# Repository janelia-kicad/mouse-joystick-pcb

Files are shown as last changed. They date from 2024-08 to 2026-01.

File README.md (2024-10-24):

- [Repository Info](#org848bbb8)
- [Images](#org07a21c3)
- [Schematic](#org23b0c57)
- [PCB](#orged9e501)
- [Bill of Materials](#org9387ca8)
- [Notes](#orgdb3690e)
- [Development](#org3c101aa)

    <!-- This file is generated automatically from metadata -->
    <!-- File edits may be overwritten! -->

# Repository Info

-   Project Name: mouse-joystick-pcb
-   Synopsis: Janelia Dudman lab PCB for the mouse joystick rig.
-   Documentation Version: 1.0.0
-   Pcb Version: 1.0
-   Enclosure Version: 1.0
-   Supplemental BOM Version: 1.0.0
-   Release Date: 2024-10-24
-   Creation Date: 2017-08-14
-   Kicad Version: 7.0.11
-   License: BSD-3-Clause
-   URL: <https://github.com/janelia-kicad/mouse-joystick-pcb>
-   Author: Peter Polidoro
-   Email: peter@polidoro.io
-   Copyright: 2024 Howard Hughes Medical Institute
-   References:
    -   <https://www.transducertechniques.com/rts-torque-sensor.aspx>
    -   <https://placidindustries.com/products/brakes/magnetic-particle-brakes/magnetic-particle-brake-b5z/>
    -   <https://www.newark.com/broadcom-limited/hedr-5421-ep111/encoder-incremental-2-ch/dp/58Y4773>
    -   <https://www.linengineering.com/products/stepper-motors/hybrid-stepper-motors/208-series/208-13-01/WO-208-13-01D>
    -   <https://www.pololu.com/product/2267>

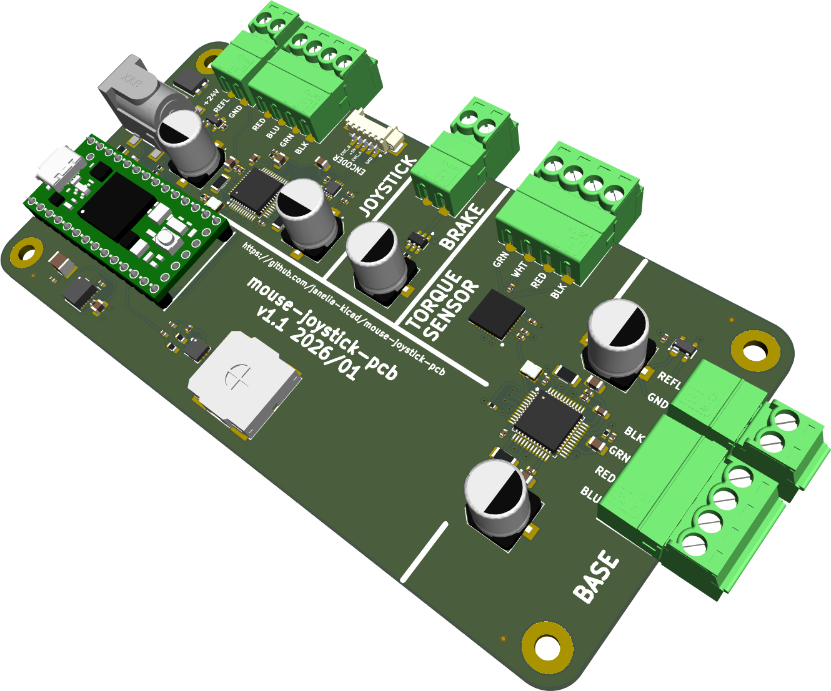
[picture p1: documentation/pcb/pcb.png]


# Images

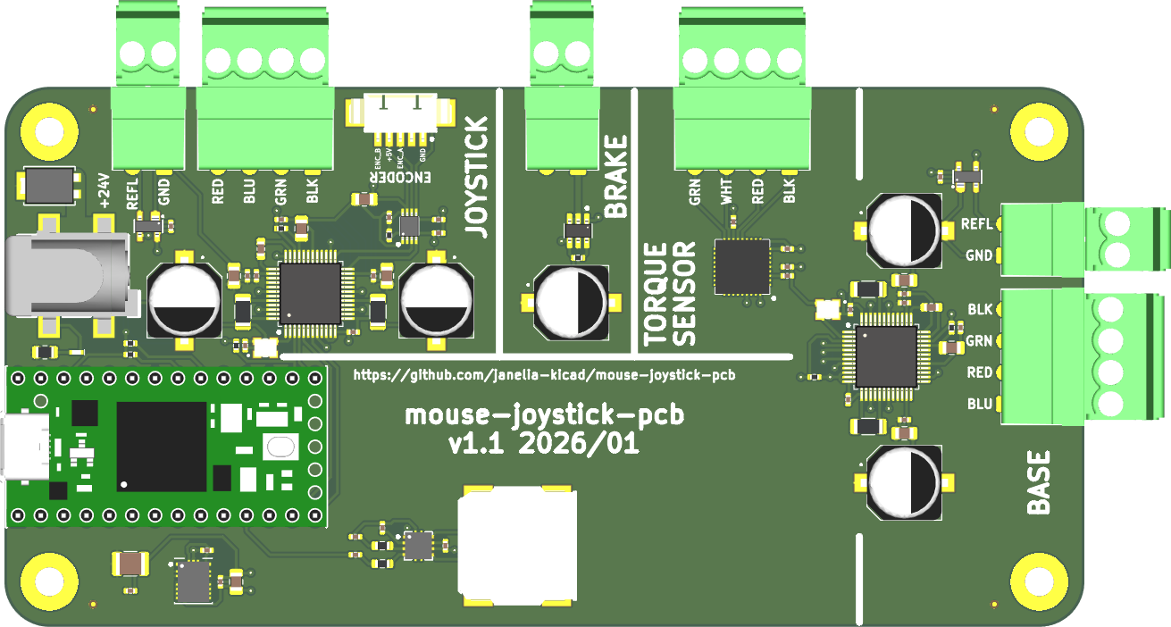
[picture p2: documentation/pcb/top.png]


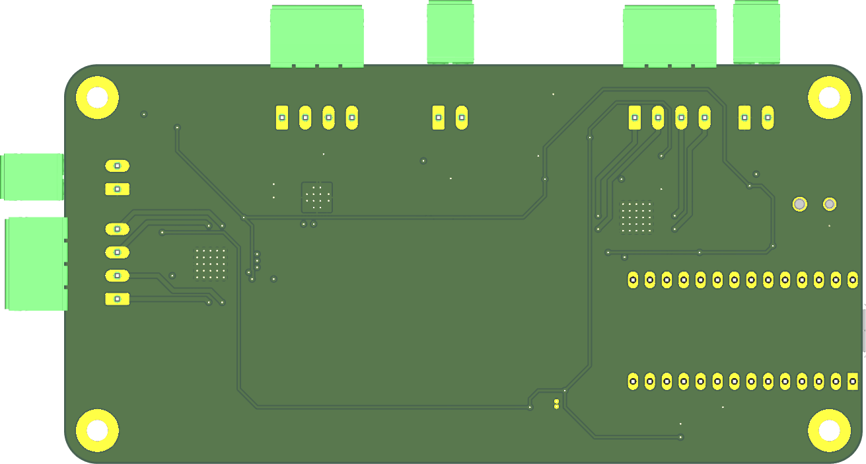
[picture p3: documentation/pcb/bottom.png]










# Schematic

[./documentation/schematic/mouse-joystick-pcb.pdf](./documentation/schematic/mouse-joystick-pcb.pdf)



















# PCB











# Bill of Materials

## Board

| Item | Synopsis | Manufacturer Part Number | Manufacturer | Quantity | Reference(s) | Package |
|---- |--- |--- |--- |--- |--- |--- |
| 1 | CONN HDR 14POS 0.1 GOLD PCB | PPPC141LFBN-RC | Sullins Connector Solutions | 1 | A401 | |
| 2 | 50V 3.3uF | FS32X335K500EGG | PSA(Prosperity Dielectrics) | 1 | C301 | 1210 |
| 3 | CAP CER 0.1UF 100V X5R | GRM155R62A104KE14D | Murata Electronics | 20 | C302 C501 C502 C504 C505 C508 C509 C510 C511 C516 C701 C702 C704 C705 C708 C709 C901 C902 C903 C904 | 0402 |
| 4 | CAP CER 1UF 25V X5R | GRT155R61E105KE01D | Murata Electronics | 2 | C303 C304 | 0402 |
| 5 | CAP CER 47UF 10V X5R | CGA0805X5R476M100MT | HRE | 3 | C305 C507 C707 | 0805 |
| 6 | CAP CER 0.022UF 100V X7R | GCM188R72A223KA37D | Murata Electronics | 2 | C503 C703 | 0603 |
| 7 | CAP CER 0.47UF 35V X5R | GRT155R6YA474KE01D | Murata Electronics | 2 | C506 C706 | 0402 |
| 8 | CAP CER 2.2UF 100V X7T 0805 | GRM21BD72A225KE01L | Murata Electronics | 5 | C512 C513 C517 C710 C711 | 0805 |
| 9 | CAP ALUM 100UF 20% 50V SMD | EEEHAH101UAP | Panasonic Electronic Components | 5 | C514 C515 C712 C713 C801 | SMD D8xL10.2mm |
| 10 | CAP CER 0.22UF 25V X6S | GRT155C81E224KE01D | Murata Electronics | 3 | C601 C602 C604 | 0402 |
| 11 | CAP CER 1UF 35V X5R | CL05A105KL5NRNC | Samsung Electro-Mechanics | 1 | C603 | 0402 |
| 12 | 50V 15A PowerDI-5 Super Barrier Rectifier | SBRT15U50SP5-13 | Diodes Incorporated | 1 | D301 | PowerDI-5 |
| 13 | LED RED CLEAR CHIP SMD | APHHS1005SURCK | Kingbright | 1 | D302 | 0402 |
| 14 | DC Power Jack 2.5A 24V 2.1MM | DC-005-2.5A-2.0-SMT | XKB Connection | 1 | J301 | SMD |
| 15 | TERM BLOCK HDR 2POS 90DEG 3.5MM | 1844210 | Phoenix Contact | 3 | J501 J701 J801 | Plugin P=3.5mm |
| 16 | TERM BLOCK HDR 4POS 90DEG 3.5MM | 1844236 | Phoenix Contact | 3 | J502 J702 J901 | Push-Pull P=3.5mm |
| 17 | CONN HEADER SMD R/A 5POS 1.25MM | 0532610571 | MOLEX | 1 | J503 | SMD |
| 18 | RES SMD 1.5K OHM 5% 500mW | ERJP06J152V | PANASONIC | 1 | R301 | 0805 |
| 19 | RES SMD 1.8K OHM 5% 100mW | ERJ2GEJ182X | PANASONIC | 4 | R401 R402 R505 R704 | 0402 |
| 20 | 0.36 250mW Current Sense Resistor | RL1206FR-070R36L | YAGEO | 2 | R501 R502 | 1206 |
| 21 | RES SMD 10 OHM 1% 62.5mW | RC0402FR-0710RL | YAGEO | 2 | R503 R703 | 0402 |
| 22 | RES 200K OHM 1% 62.5mW | 0402WGF2003TCE | UNI-ROYAL(Uniroyal Elec) | 1 | R504 | 0402 |
| 23 | RES SMD 40k OHM 1% 100mW | SCR0603F40K | VO | 2 | R601 R602 | 0603 |
| 24 | 0.12 750mW Current Sense Resistor | KRL1632E-M-R120-F-T5 | SUSUMU | 2 | R701 R702 | 1206 |
| 25 | RES 30 OHM 1% 62.5mW | CR0402FF30R0G | LIZ Elec | 1 | R801 | 0402 |
| 26 | SPEAKER 8OHM 700MW | KLJ-01304T-08R07W | KELIKING | 1 | SP601 | |
| 27 | DC-DC 5V 600mA Output 3-65V Input | TPSM365R6V5RDNR | Texas Instruments | 1 | U301 | QFN-11(3.5x4.5) |
| 28 | IC SWITCH DEBOUNCER | MAX6816EUS+T | Analog Devices Inc./Maxim Integrated | 2 | U501 U701 | SOT-143 |
| 29 | IC MTR DRV BIPOLAR 5.5-46V | TMC5130A-TA | Analog Devices Inc./Maxim Integrated | 2 | U502 U702 | TQFP-48-EP(7x7) |
| 30 | IC TRANSLTR BIDIRECTIONAL 2 CHAN | LSF0102DCUR | Texas Instruments | 1 | U503 | VSSOP-8-0.5mm |
| 31 | IC AMP CLASS AB MONO 1.7W | TPA6204A1DRBR | Texas Instruments | 1 | U601 | QFN-8-EP(3x3) |
| 32 | IC LED DRVR LIN PWM 200MA | BCR421UE6327 | Infineon Technologies | 1 | U801 | SC-74-6 |
| 33 | IC SIGNAL COND ANLG | PGA305ARHHR | Texas Instruments | 1 | U901 | VQFN-36-EP(6x6) |
| 34 | XTAL OSC XO 16MHZ 3.3V HCMOS SMD | ECS-2520S33-160-FN-TR | ECS Inc. | 2 | X501 X701 | SMD2520-4P |

## Supplemental

| Item | Synopsis | Manufacturer Part Number | Manufacturer | Quantity | Cost  | Total |
|---- |--- |--- |--- |--- |----- |----- |
| 1 | AC/DC DESKTOP ADAPTER 24V 65W | SDI65-24-UC-P5 | CUI Inc. | 1 | 29.26 | 29.26 |
| 2 | TEENSY 4.0 (HEADERS) | DEV-16997 | SparkFun Electronics | 1 | 28.50 | 28.50 |
| 3 | CBL USB2.0 A PLG-MCR B PLG 3.28' | 102-1492-BL-F0100 | CNC Tech | 1 | 6.06  | 6.06  |
| 4 | TERM BLOCK PLUG 4POS STR 3.5MM | 1840382 | Phoenix Contact | 3 | 6.27  | 18.81 |
| 5 | TERM BLOCK PLUG 2POS STR 3.5MM | 1840366 | Phoenix Contact | 3 | 3.83  | 11.49 |
| 6 | PICOBLADE 5 CIRCUIT 300MM | 0151340503 | Molex | 1 | 5.18  | 5.18  |
| 7 | Supplemental BOM Version: 1.0.0  | | | | Total | 99.30 |

# Notes

## Actuators

### Stepper Motors

1.  Big

    SOYO SY42STH38-1684A

2.  Little

    Lin Engineering WO-208-13-01D-RO

### Brake

Placid Industries B5Z-24-1R Magnetic Particle Brake

-   Current control 0-0.049 A at 24 V

## Sensors

### Torque Sensor

Transducer Techniques RTS-5

-   wheatstone bridge

### Encoder

Newark HEDR-5421-EP111

-   Two channel quadrature

### Limit Switches

MiSUMi D2F-01FL

-   Normally open or normally closed

# Development

## Install Guix

[Install Guix](https://guix.gnu.org/manual/en/html_node/Binary-Installation.html)

## Generate Output from KiCad

### Remove previous versions

```sh
rm -rf ./documentation/3dmodels/* && rm -rf ./documentation/bom/* && rm -rf ./documentation/fabrication/* && rm -rf ./documentation/pcb/* && rm -rf ./documentation/schematic/*pcb
```

### Images

1.  3D Viewer

    Output directory: ../documentation/pcb
    
    -   pcb.png
    -   top.png
    -   bottom.png
    -   front.png
    -   back.png
    -   left.png
    -   right.png

2.  Trim

        make trimmed-images

3.  Schematic PDF

    File -> Plot
    
    Output directory: ../documentation/schematic
    
    Plot All Pages
    
    -   Output format PDF
    -   Page Size = Schematic size
    -   Plot drawing sheet
    -   Output mode = Color
    -   Color theme = KiCad Default
    -   Default line width = 0.006 in

4.  Schematic SVG

    File -> Plot
    
    Output directory: ../documentation/schematic
    
    Plot All Pages
    
    -   Output format SVG
    -   Page Size = Schematic size
    -   Plot drawing sheet
    -   Output mode = Color
    -   Color theme = Solarized Light
    -   Default line width = 0.012 in

5.  PCB SVG

    Add Edge.Cuts, holes, and dimensions to User.Drawings
    
    File -> Plot
    
    Output directory: ../documentation/pcb
    
    -   Plot format SVG
    -   Include Layers
        -   User.Drawings
        -   F.Silkscreen
        -   B.Silkscreen
        -   F.Fab
        -   B.Fab
    -   Plot on All Layers
        -   Edge.Cuts
    -   Plot footprint values
    -   Plot reference designators
    -   SVG Options
        -   Precision = 4
        -   Output mode = color
    
        make cropped-svg

### Fabrication Files

1.  Gerbers

    File -> Fabrication Outputs -> Gerbers (.gbr)
    
    Output directory: ../documentation/fabrication/gerbers
    
    Include Layers:
    
    -   F.Cu
    -   F.Paste
    -   F.Silks
    -   F.Mask
    -   F.Fab
    -   B.Cu
    -   B.Paste
    -   B.Silks
    -   B.Mask
    -   B.Fab
    -   Edge.Cuts - (contain the board outline/cutouts.)
    -   In1.Cu, In2.Cu … - (needed for 4/6 layer designs.)
    
    Options:
    
    -   Select Plot reference designators, otherwise designators will not appear on silkscreen layers.
    -   Select Check zone fills before plotting
    -   Select Use Protel filename extensions, this is recommended as JLCPCB prefers Protel filename extensions.
    -   Select Subtract soldermask from silkscreen, this ensures no silkscreen on pads.
    -   Coordinate format 4.6 unit mm

2.  Drill and Map Files

    Output directory: ../documentation/fabrication/gerbers
    
    Options:
    
    -   Excellon drill file format
    -   Check Use alternate drill mode for "Oval Holes Drill Mode".
    -   Check Absolute for "Drill Origin".
    -   Check Millimeters for "Drill Units".
    -   Check Decimal format for "Zeros Format".
    -   Gerber X2 map file format
    
    Zip gerber files
    
        zip ./documentation/fabrication/gerbers.zip ./documentation/fabrication/gerbers/*

3.  BOM

    Generate BOM from schematic editor using blank command line to create bom xml file.

4.  POS

    File -> Fabrication Outputs -> Component Placement (.pos)
    
    Output directory: ../documentation/fabrication/
    
    Settings:
    
    -   Format = CSV
    -   Units = Millimeters
    -   Files = Single file for board
    -   Do not use drill/place file origin
    
    Modify pos files:
    
    -   Ref -> Designator
    -   PosX -> Mid X
    -   PosY -> Mid Y
    -   Rot -> Rotation
    -   Side -> Layer

5.  Step

    File -> Export -> Step
    
    Output directory: ../documentation/3dmodels/pcb.step
    
    -   Drill/place file origin
    -   Overwrite old file
    -   Standard Board outline chaining tolerance

## Edit metadata.org

    make metadata-edits

## Tangle metadata.org

    make metadata

## Edit project

    make kicad-edits
    exit

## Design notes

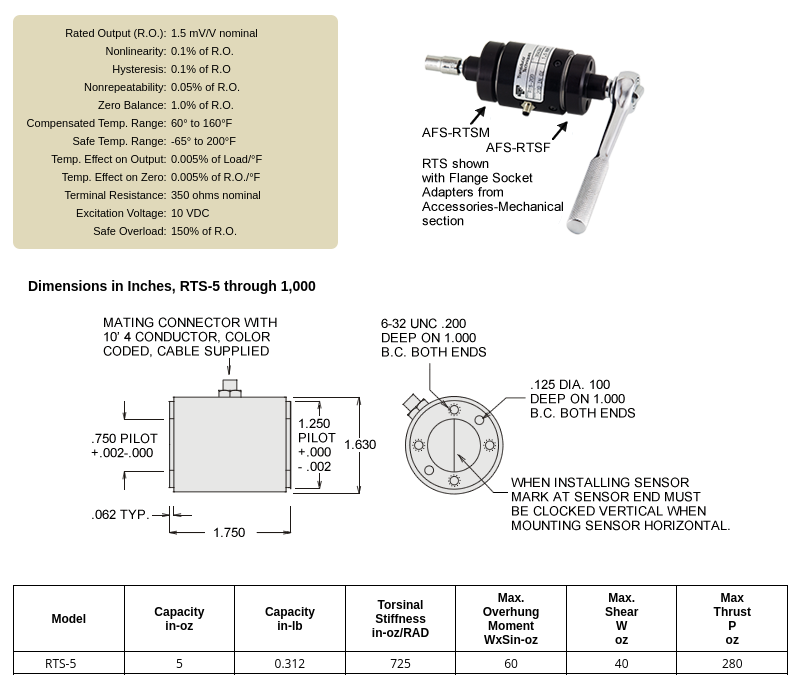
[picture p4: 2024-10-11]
documentation/datasheets/torque-sensor-specs.png

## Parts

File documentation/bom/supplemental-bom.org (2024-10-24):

#+OPTIONS: toc:nil title:nil num:nil ^:nil
#+LATEX_HEADER: \usepackage{adjustbox}
#+LATEX_HEADER: \usepackage[margin=2cm]{geometry}
* Supplemental BOM
- Project Name: mouse-joystick-pcb
- Synopsis: Janelia Dudman lab PCB for the mouse joystick rig.
- Release Date: 2024-10-24
- URL: https://github.com/janelia-kicad/mouse-joystick-pcb
- Author: Peter Polidoro
- Email: peter@polidoro.io
#+BEGIN_TABLE
#+LATEX: \adjustbox{max width=\linewidth}{
#+ATTR_LATEX: :center nil
| Item | Synopsis                                               | Manufacturer Part Number | Manufacturer         | Quantity |  Cost | Total |
|------+--------------------------------------------------------+--------------------------+----------------------+----------+-------+-------|
|    1 | AC/DC DESKTOP ADAPTER 24V 65W                          | SDI65-24-UC-P5           | CUI Inc.             |        1 | 29.26 | 29.26 |
|    2 | TEENSY 4.0 (HEADERS)                                   | DEV-16997                | SparkFun Electronics |        1 | 28.50 | 28.50 |
|    3 | CBL USB2.0 A PLG-MCR B PLG 3.28'                       | 102-1492-BL-F0100        | CNC Tech             |        1 |  6.06 |  6.06 |
|    4 | TERM BLOCK PLUG 4POS STR 3.5MM                         | 1840382                  | Phoenix Contact      |        3 |  6.27 | 18.81 |
|    5 | TERM BLOCK PLUG 2POS STR 3.5MM                         | 1840366                  | Phoenix Contact      |        3 |  3.83 | 11.49 |
|    6 | PICOBLADE 5 CIRCUIT 300MM                              | 0151340503               | Molex                |        1 |  5.18 |  5.18 |
|------+--------------------------------------------------------+--------------------------+----------------------+----------+-------+-------|
|    7 | Supplemental BOM Version: 1.0.0 |                          |                      |          | Total | 99.30 |
#+TBLFM: $1=@#-1::$7=$5*$6;%0.2f::@>$7=vsum(@2..@-1);%0.2f
#+LATEX: }
#+END_TABLE

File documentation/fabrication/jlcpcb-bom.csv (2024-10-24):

Comment | Designator | Footprint | LCSC
CONN HDR 14POS 0.1 GOLD PCB | A401
50V 3.3uF | C301 | 1210 | C1021610
CAP CER 0.1UF 100V X5R | C302 C501 C502 C504 C505 C508 C509 C510 C511 C516 C701 C702 C704 C705 C708 C709 C901 C902 C903 C904 | 0402 | C162178
CAP CER 1UF 25V X5R | C303 C304 | 0402 | C711085
CAP CER 47UF 10V X5R | C305 C507 C707 | 0805 | C6119904
CAP CER 0.022UF 100V X7R | C503 C703 | 0603 | C161234
CAP CER 0.47UF 35V X5R | C506 C706 | 0402 | C711580
CAP CER 2.2UF 100V X7T 0805 | C512 C513 C517 C710 C711 | 0805 | C2981733
CAP ALUM 100UF 20% 50V SMD | C514 C515 C712 C713 C801 | SMD D8xL10.2mm | C336425
CAP CER 0.22UF 25V X6S | C601 C602 C604 | 0402 | C126623
CAP CER 1UF 35V X5R | C603 | 0402 | C307413
50V 15A PowerDI-5 Super Barrier Rectifier | D301 | PowerDI-5 | C211388
LED RED CLEAR CHIP SMD | D302 | 0402 | C2852592
DC Power Jack 2.5A 24V 2.1MM | J301 | SMD | C2880543
TERM BLOCK HDR 2POS 90DEG 3.5MM | J501 J701 J801 | Plugin P=3.5mm | C3584780
TERM BLOCK HDR 4POS 90DEG 3.5MM | J502 J702 J901 | Push-Pull P=3.5mm | C480590
CONN HEADER SMD R/A 5POS 1.25MM | J503 | SMD | C17256390
RES SMD 1.5K OHM 5% 500mW | R301 | 0805 | C417005
RES SMD 1.8K OHM 5% 100mW | R401 R402 R505 R704 | 0402 | C409855
0.36 250mW Current Sense Resistor | R501 R502 | 1206 | C327079
RES SMD 10 OHM 1% 62.5mW | R503 R703 | 0402 | C138066
RES 200K OHM 1% 62.5mW | R504 | 0402 | C25764
RES SMD 40k OHM 1% 100mW | R601 R602 | 0603 | C3016445
0.12 750mW Current Sense Resistor | R701 R702 | 1206 | C2076122
RES 30 OHM 1% 62.5mW | R801 | 0402 | C3036820
SPEAKER 8OHM 700MW | SP601 |  | C18186315
DC-DC 5V 600mA Output 3-65V Input | U301 | QFN-11(3.5x4.5) | C19078014
IC SWITCH DEBOUNCER | U501 U701 | SOT-143 | C41637
IC MTR DRV BIPOLAR 5.5-46V | U502 U702 | TQFP-48-EP(7x7) | C188832
IC TRANSLTR BIDIRECTIONAL 2 CHAN | U503 | VSSOP-8-0.5mm | C964636
IC AMP CLASS AB MONO 1.7W | U601 | QFN-8-EP(3x3) | C12400
IC LED DRVR LIN PWM 200MA | U801 | SC-74-6 | C112923
IC SIGNAL COND ANLG | U901 | VQFN-36-EP(6x6) | C2678416
XTAL OSC XO 16MHZ 3.3V HCMOS SMD | X501 X701 | SMD2520-4P | C2451298

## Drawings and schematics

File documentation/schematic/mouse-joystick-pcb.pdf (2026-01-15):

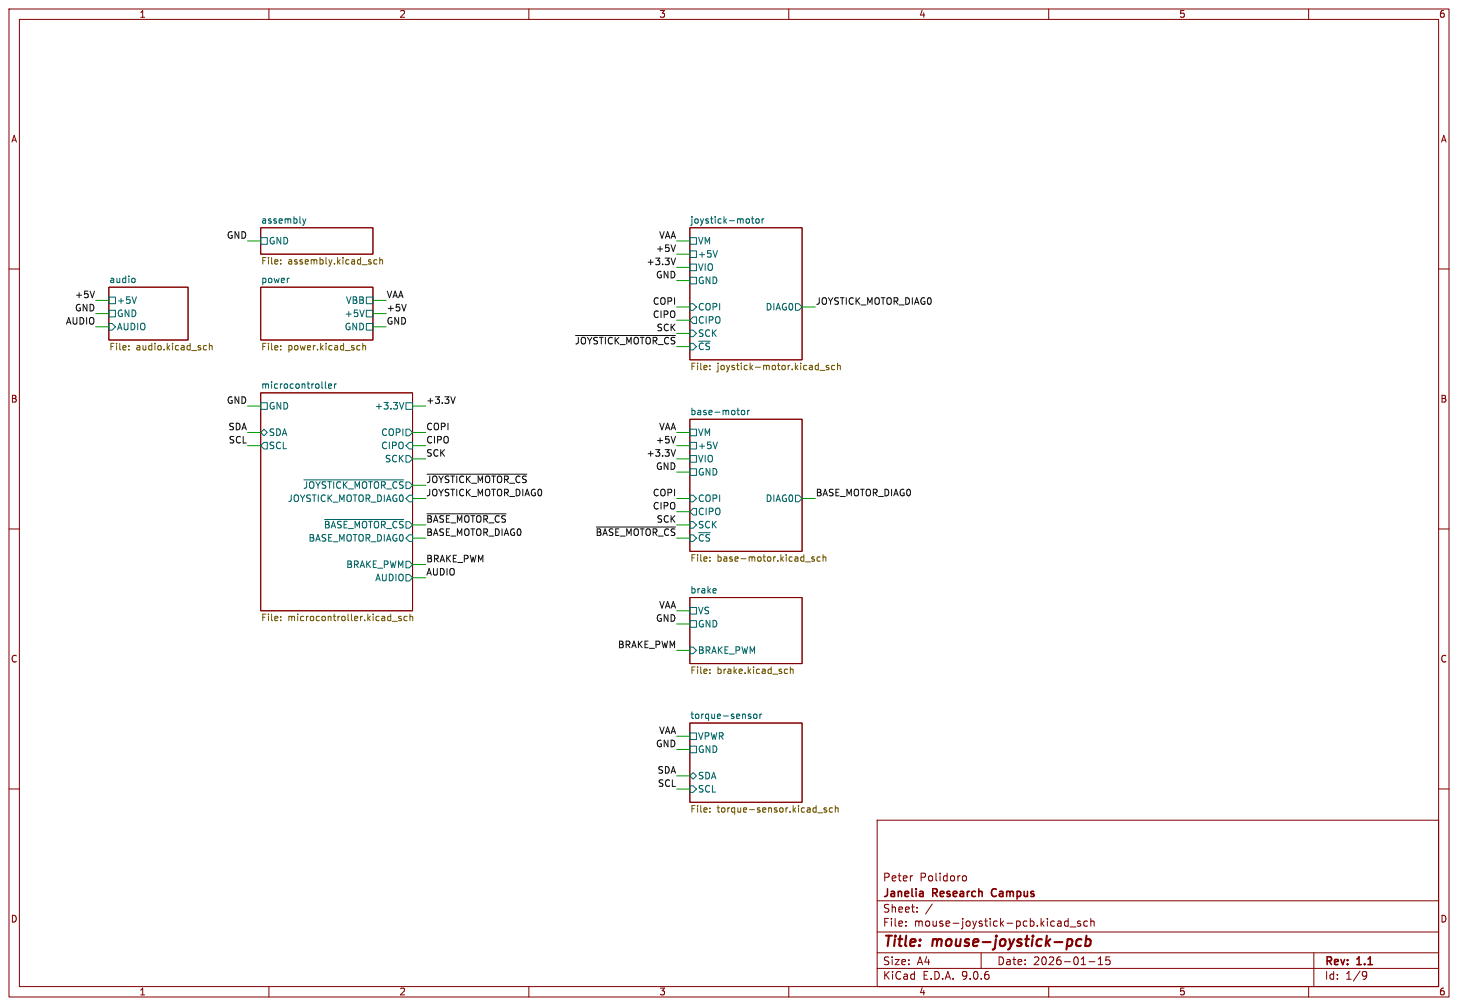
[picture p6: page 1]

assembly File: assembly.kicad_sch VBB

joystick-motor File: joystick-motor.kicad_sch GND

VAA
~{CS} SCK COPI CIPO
torque-sensor File: torque-sensor.kicad_sch GND

base-motor File: base-motor.kicad_sch VSGND

Id: 1/9 Title: mouse-joystick-pcb

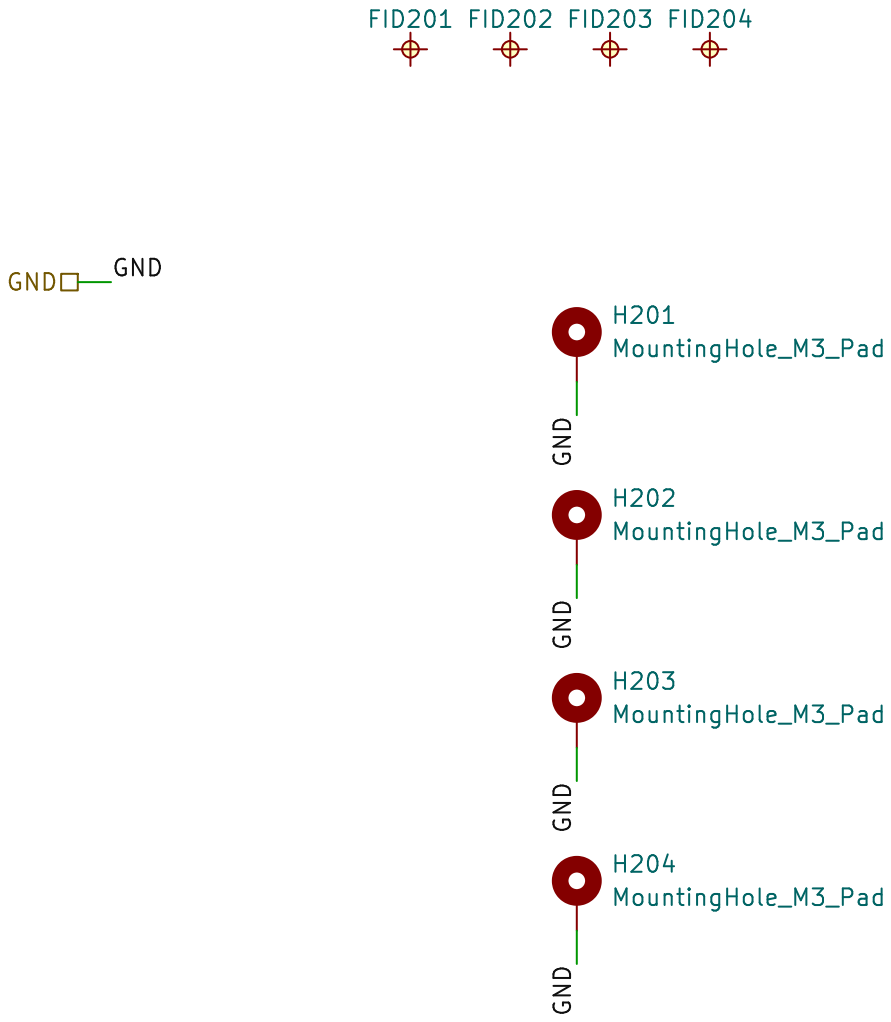
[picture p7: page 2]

Id: 2/9 Title: mouse-joystick-pcb

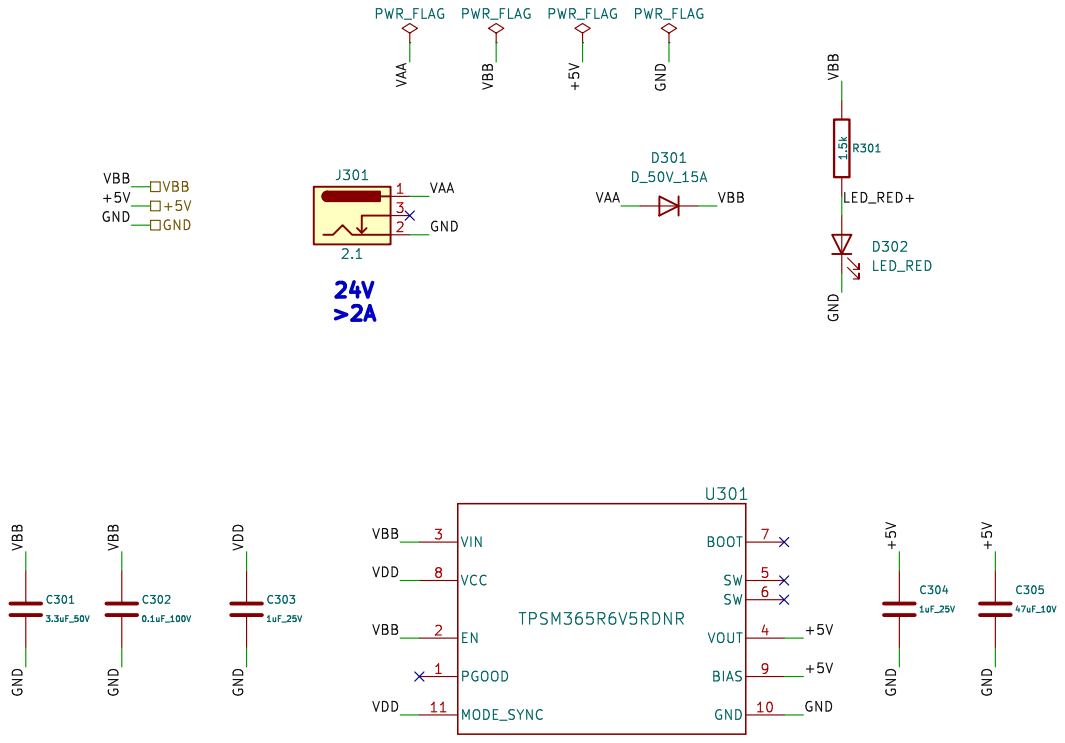
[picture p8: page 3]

LED_RED+ VBB VBB GND VBB

Id: 3/9 Title: mouse-joystick-pcb

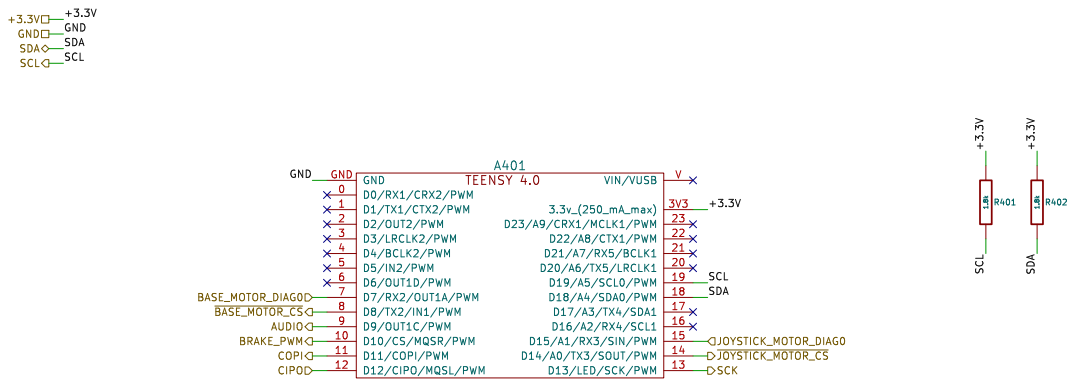
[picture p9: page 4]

Id: 4/9 Title: mouse-joystick-pcb

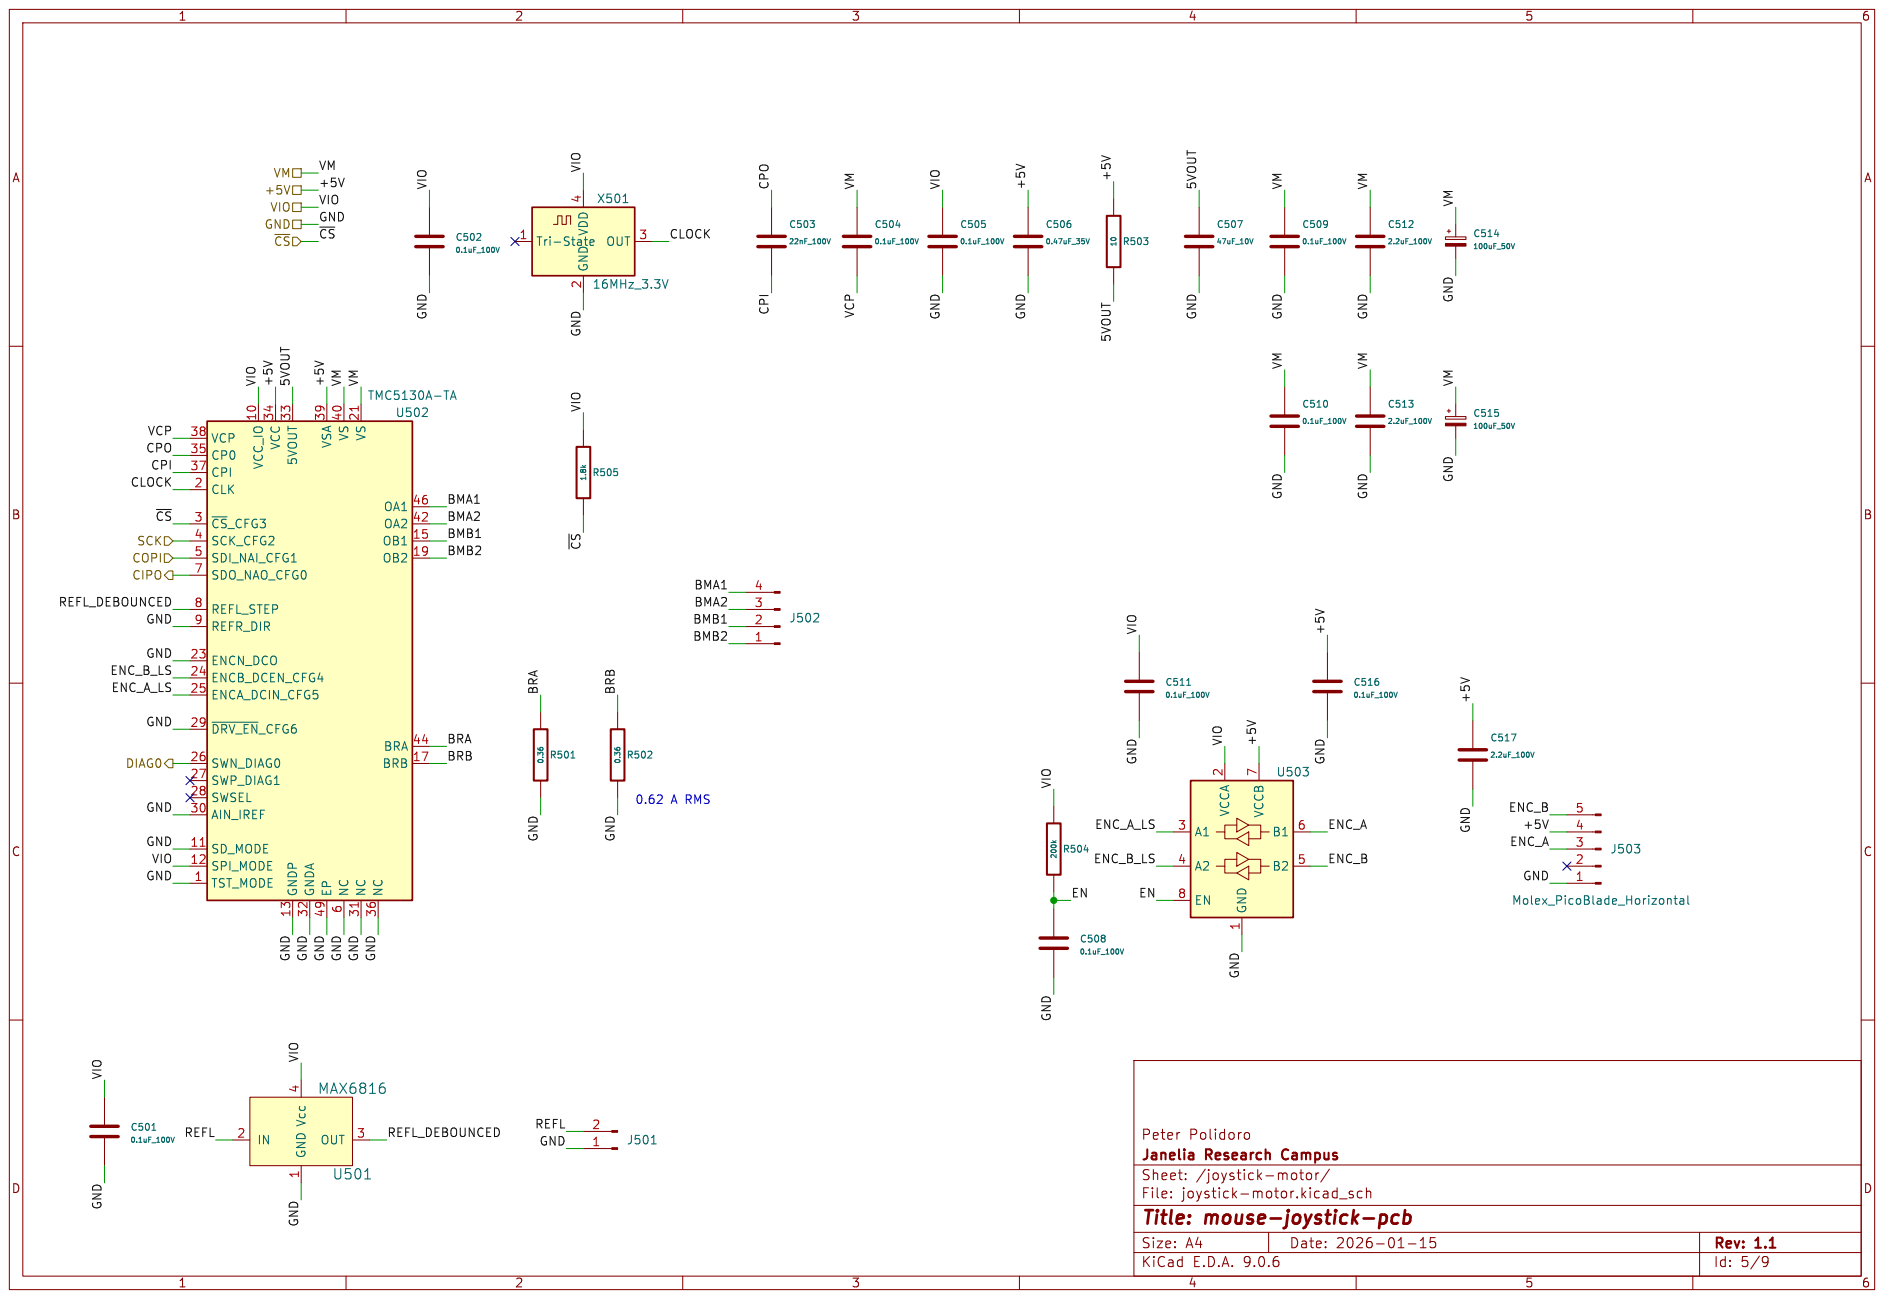
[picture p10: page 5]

Id: 5/9 Title: mouse-joystick-pcb

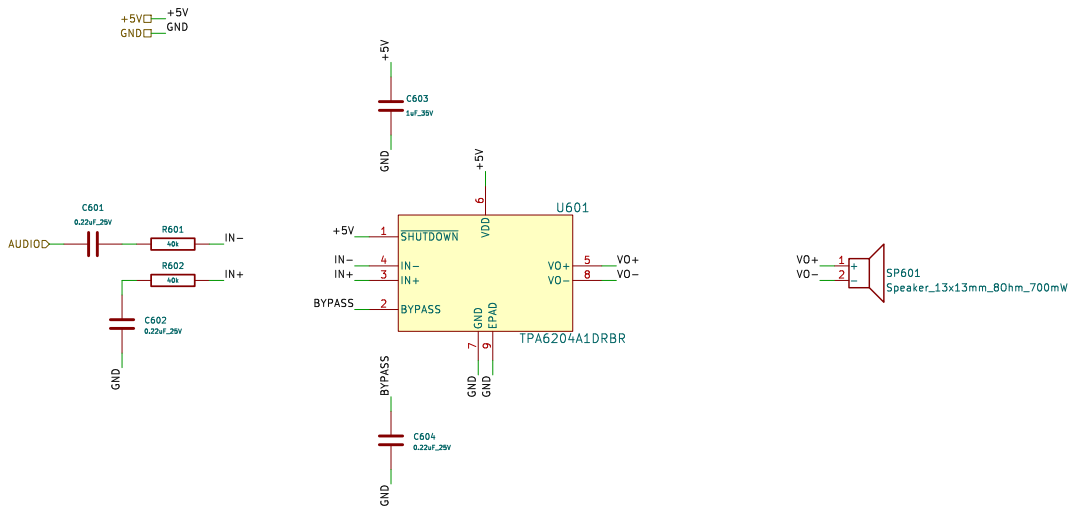
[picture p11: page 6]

Id: 6/9 Title: mouse-joystick-pcb

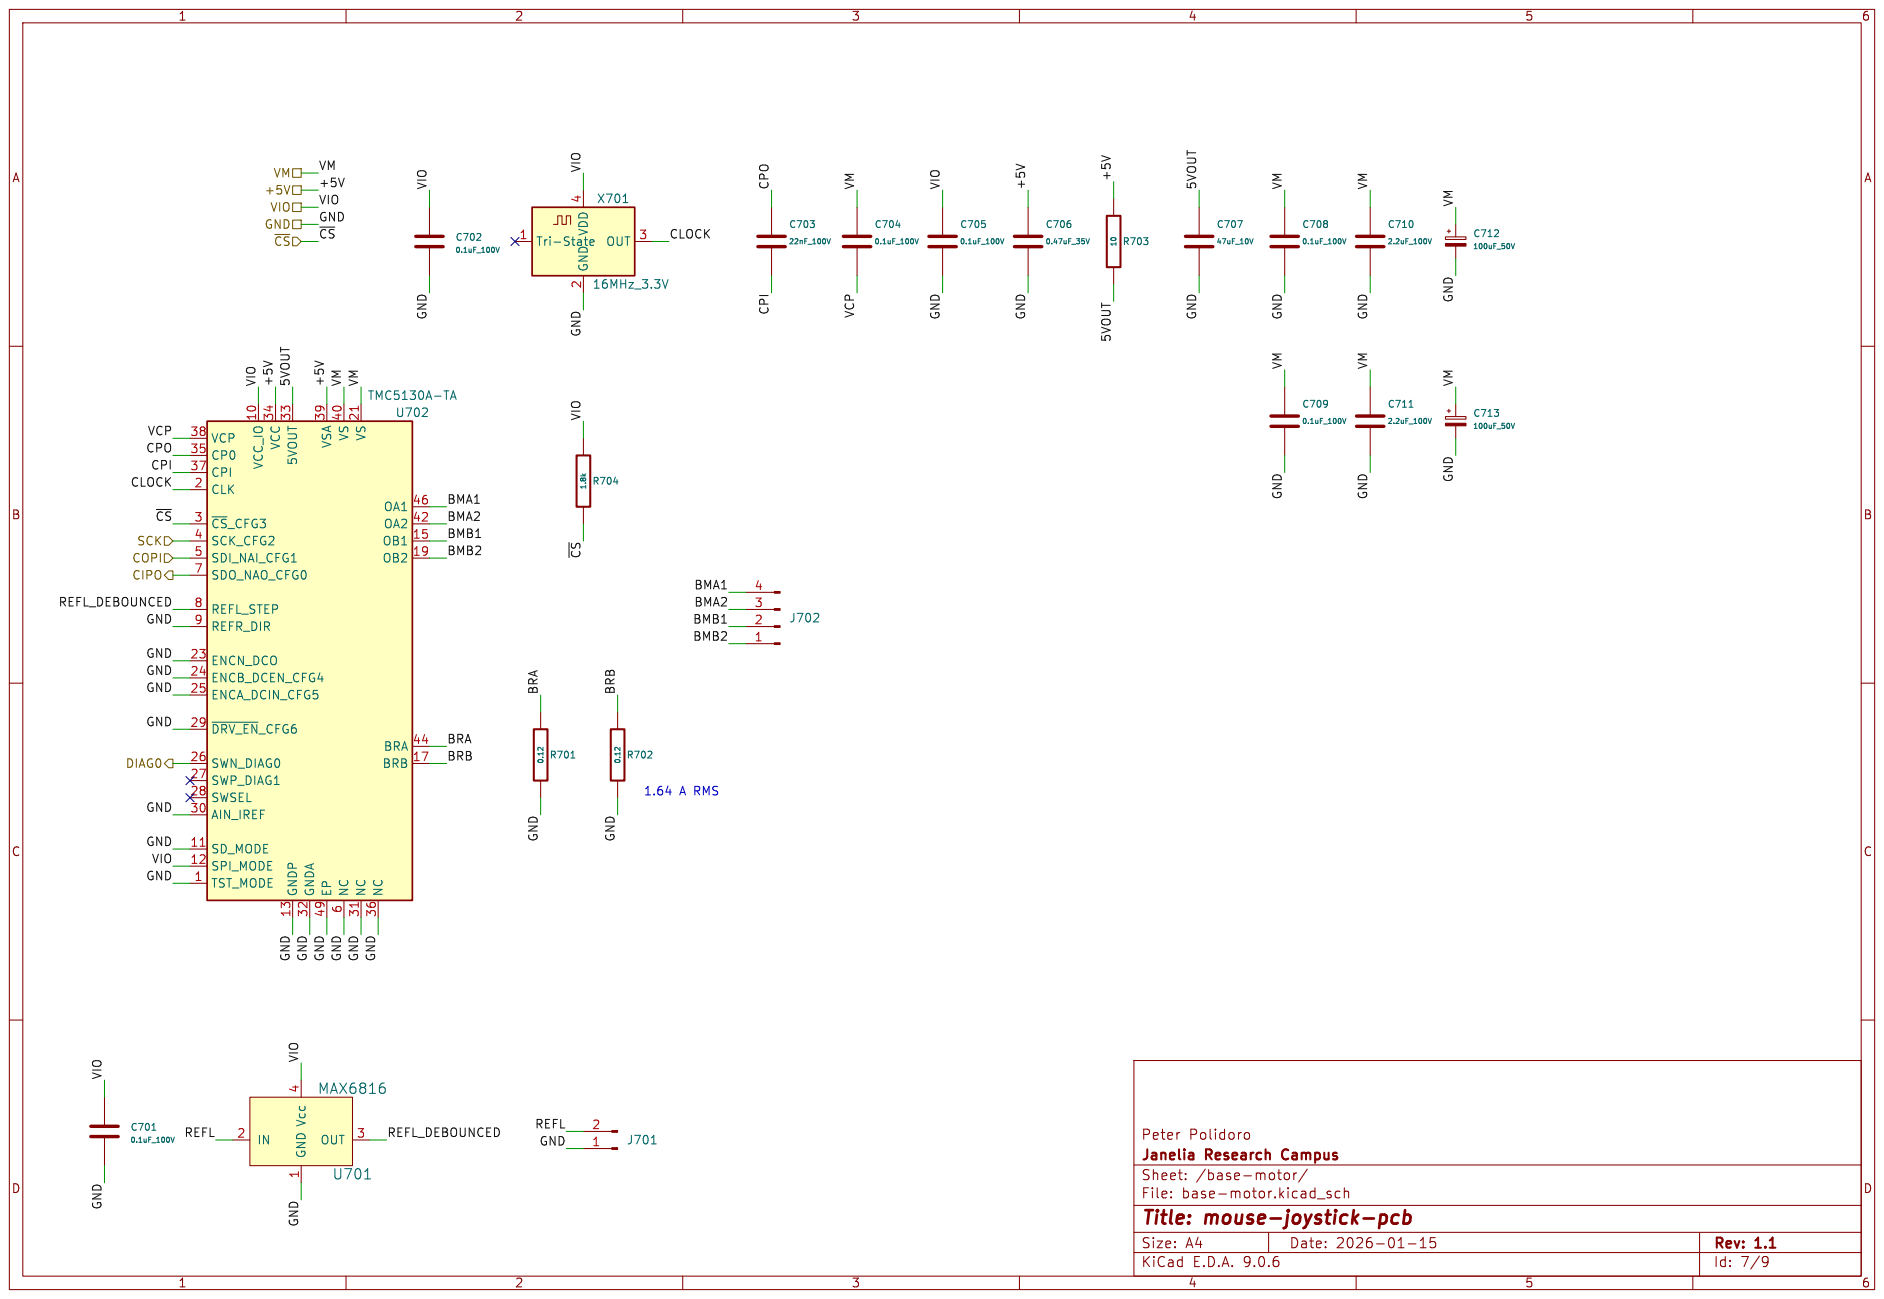
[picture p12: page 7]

Id: 7/9 Title: mouse-joystick-pcb

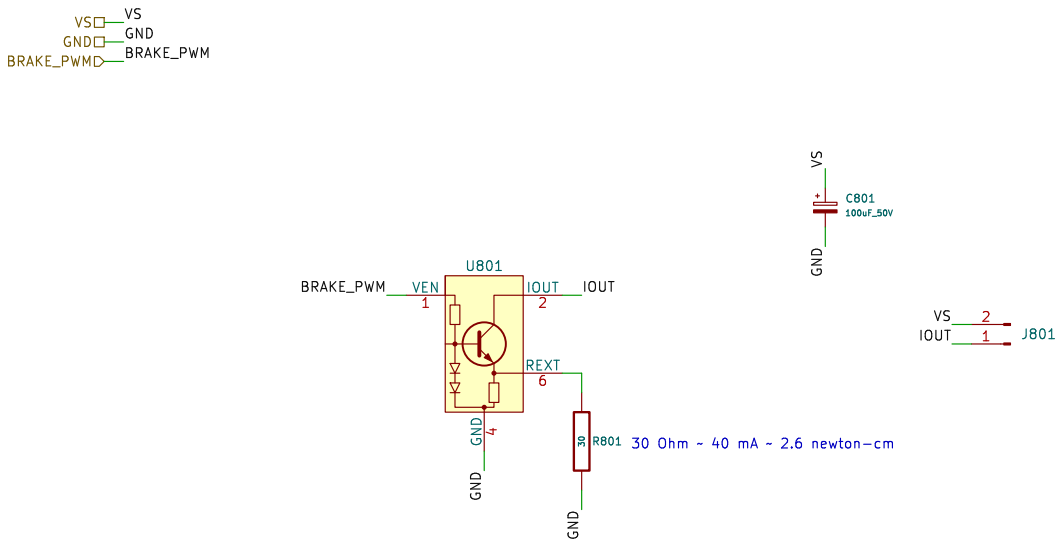
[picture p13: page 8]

30 Ohm ~ 40 mA ~ 2.6 newton-cm

Id: 8/9 Title: mouse-joystick-pcb

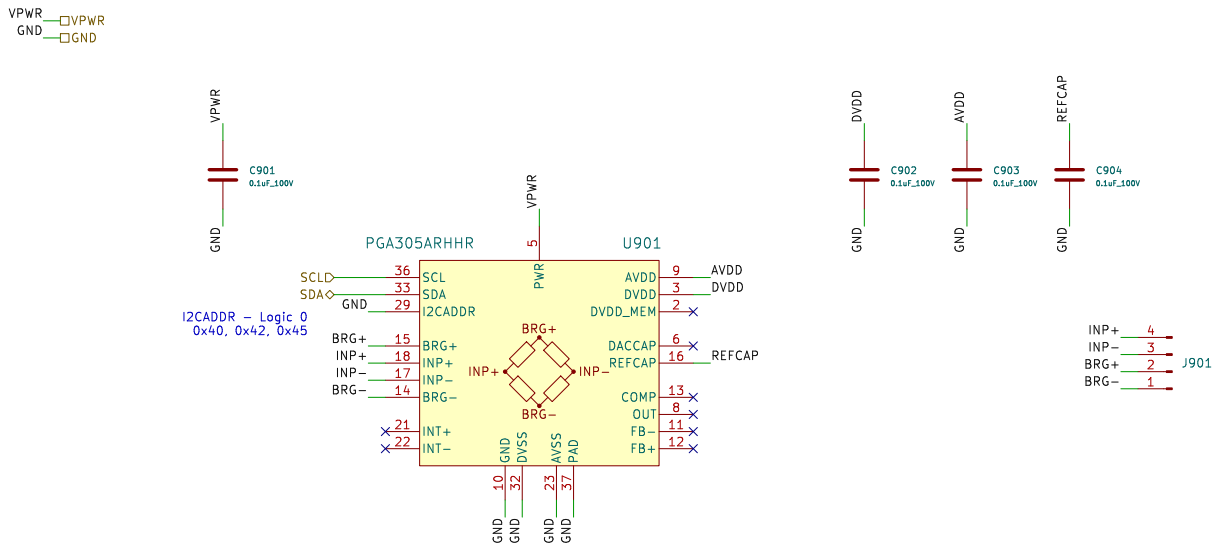
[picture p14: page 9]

5 AVSS 23 PAD 37 DVDD_MEM 2 OUT 8 FB- 11 FB+ 12 SCL 36 AVDD 9 DVDD 3 DACCAP 6 REFCAP 16 COMP 13 PGA305ARHHR U901

Id: 9/9 Title: mouse-joystick-pcb

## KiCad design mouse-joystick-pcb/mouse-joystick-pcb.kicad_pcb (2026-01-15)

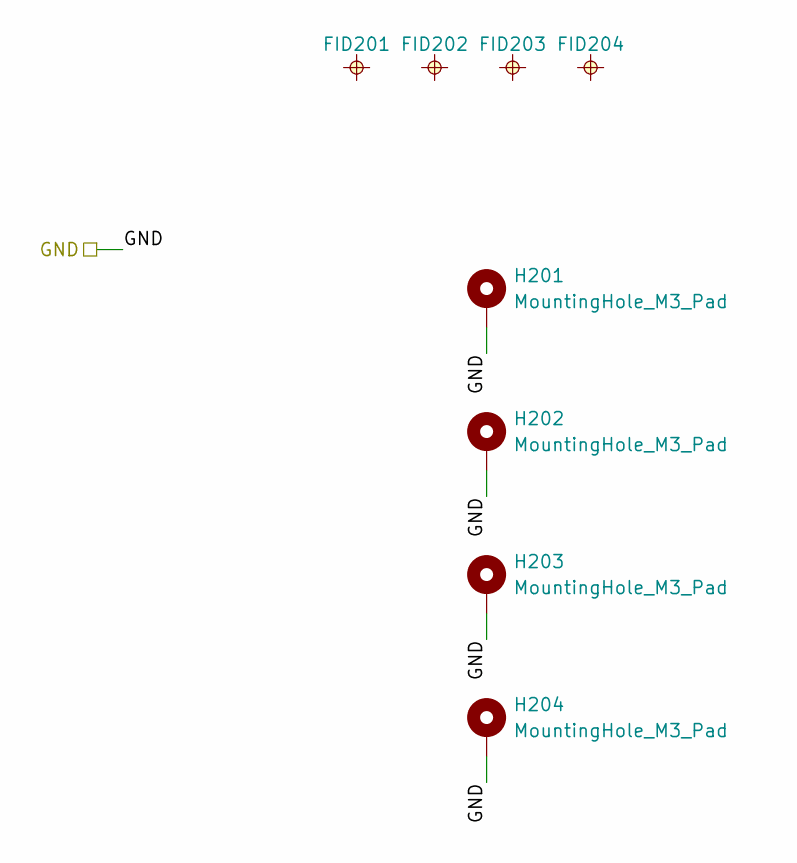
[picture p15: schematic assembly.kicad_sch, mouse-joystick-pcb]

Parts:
FID201, FID202, FID203, FID204: FIDUCIAL_0.5mm_MASK1mm; FIDUCIAL_0.5mm_Mask1mm
H201, H202, H203, H204: MountingHole_M3_Pad; MountingHole_3.2mm_M3_Pad

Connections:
/GND: H201.1, H202.1, H203.1, H204.1; also elsewhere on the board

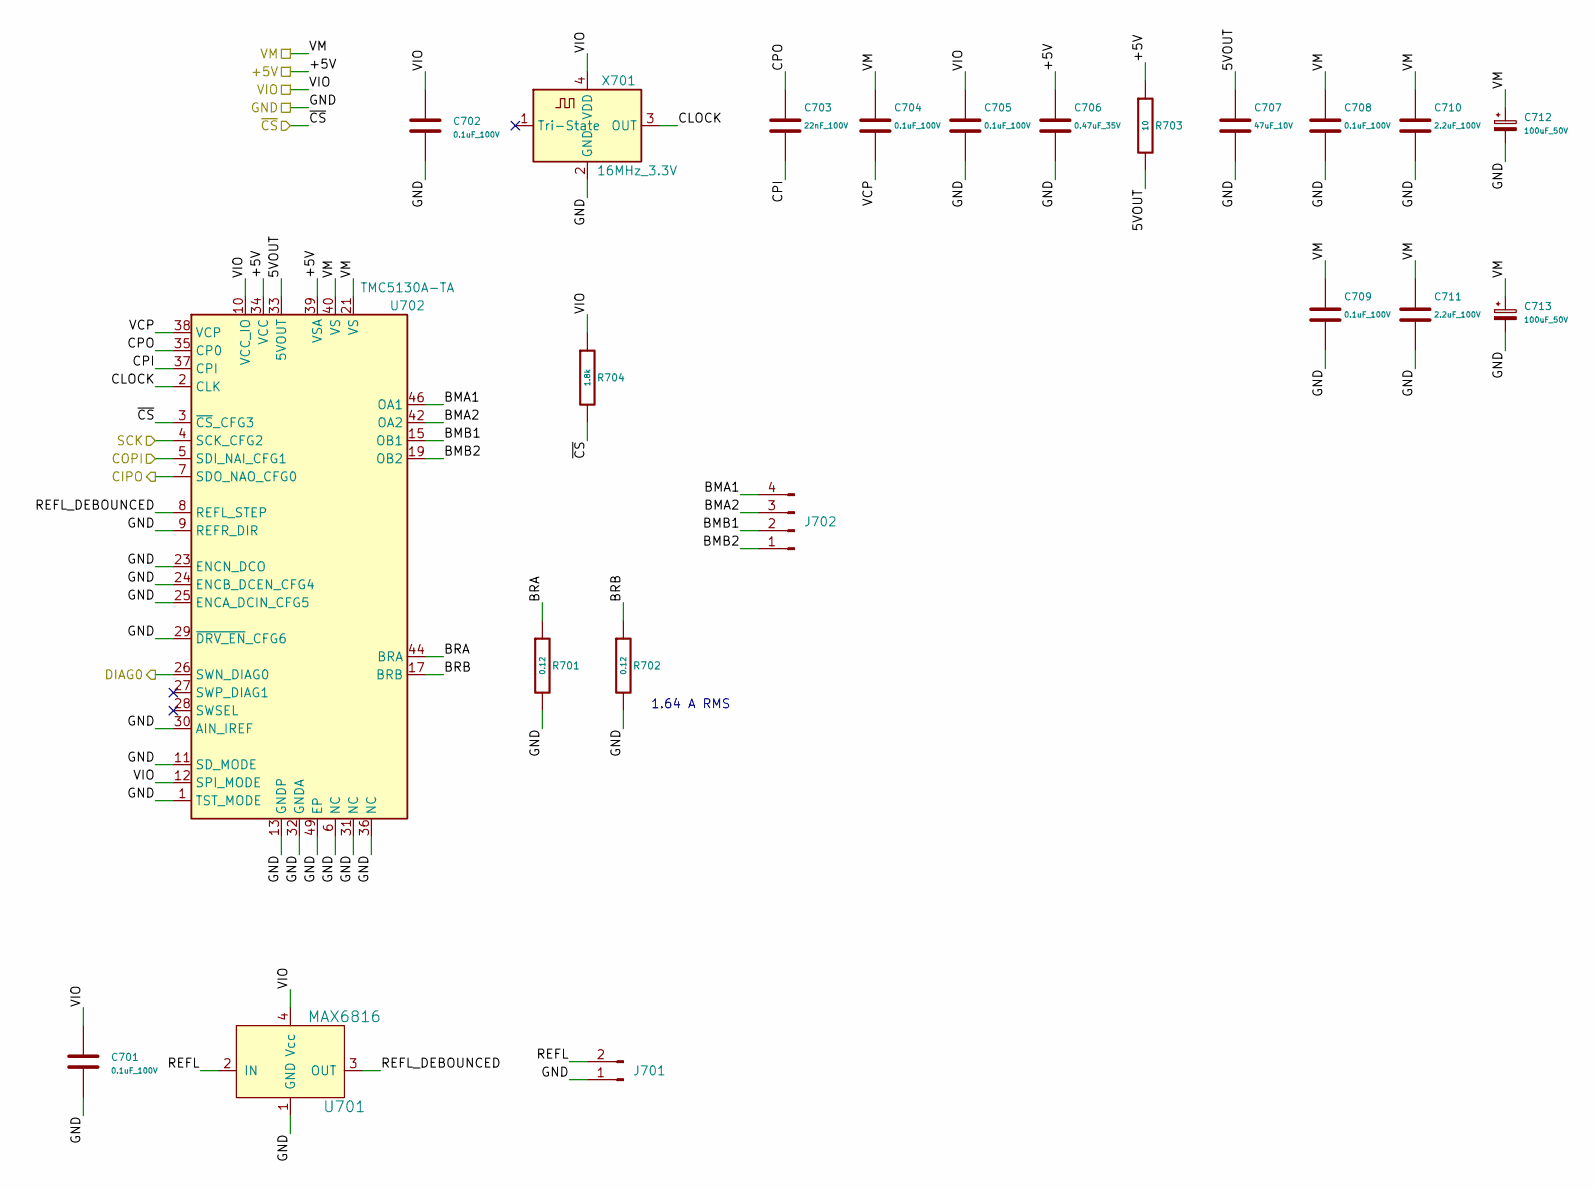
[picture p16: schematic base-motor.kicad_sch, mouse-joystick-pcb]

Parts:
C701, C702, C704, C705, C708, C709: 0.1uF_100V; C_0402_1005Metric; Manufacturer Part Number GRM155R62A104KE14D; LCSC C162178
C703: 22nF_100V; C_0603_1608Metric; Manufacturer Part Number GCM188R72A223KA37D; LCSC C161234
C706: 0.47uF_35V; C_0402_1005Metric; Manufacturer Part Number GRT155R6YA474KE01D; LCSC C711580
C707: 47uF_10V; C_0805_2012Metric; Manufacturer Part Number CGA0805X5R476M100MT; LCSC C6119904
C710, C711: 2.2uF_100V; C_0805_2012Metric; Manufacturer Part Number GRM21BD72A225KE01L; LCSC C2981733
C712, C713: 100uF_50V; CAP_EEEHAH101UAP; Manufacturer Part Number EEEHAH101UAP; LCSC C336425
J701: Conn_01x02_P3.5mm_TBH_Horizontal_Screw; PhoenixContact_MC_1,5_2-G-3.5_1x02_P3.50mm_Horizontal_Screw; Manufacturer Part Number 1844210; LCSC C3584780
J702: Conn_01x04_P3.5mm_TBH_Horizontal_Screw; PhoenixContact_MC_1,5_4-G-3.5_1x04_P3.50mm_Horizontal_Screw; Manufacturer Part Number 1844236; LCSC C480590
R701, R702: 0.12; R_1206_3216Metric; Manufacturer Part Number KRL1632E-M-R120-F-T5; LCSC C2076122
R703: 10; R_0402_1005Metric; Manufacturer Part Number RC0402FR-0710RL; LCSC C138066
R704: 1.8k; R_0402_1005Metric; Manufacturer Part Number ERJ2GEJ182X; LCSC C409855
U701: MAX6816; SOT192P237X122-4N; Manufacturer Part Number MAX6816EUS+T; LCSC C41637
U702: TMC5130A-TA; TQFP-48-1EP_7x7mm_P0.5mm_EP5x5mm_ThermalVias; Manufacturer Part Number TMC5130A-TA; LCSC C188832
X701: 16MHz_3.3V; OSC_ECS-2520S33-160-FN-TR; Manufacturer Part Number ECS-2520S33-160-FN-TR; LCSC C2451298

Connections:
/+3.3V: C701.1, C702.1, C705.1, R704.1, U701.4 (Vcc), U702.10 (VCC_IO), U702.12 (SPI_MODE), X701.4 (VDD); also elsewhere on the board
/+5V: C706.1, R703.1, U702.34 (VCC), U702.39 (VSA); also elsewhere on the board
/BASE_MOTOR_DIAG0: U702.26 (SWN_DIAG0); also elsewhere on the board
/CIPO: U702.7 (SDO_NAO_CFG0); also elsewhere on the board
/COPI: U702.5 (SDI_NAI_CFG1); also elsewhere on the board
/GND: C701.2, C702.2, C705.2, C706.2, C707.2, C708.2, C709.2, C710.2, C711.2, C712.2, C713.2, J701.1, R701.2, R702.2, U701.1 (GND), U702.1 (TST_MODE), U702.6 (NC), U702.9 (REFR_DIR), U702.11 (SD_MODE), U702.13 (GNDP), U702.23 (ENCN_DCO), U702.24 (ENCB_DCEN_CFG4), U702.25 (ENCA_DCIN_CFG5), U702.29 (~DRV_EN_CFG6), U702.30 (AIN_IREF), U702.31 (NC), U702.32 (GNDA), U702.36 (NC), U702.48 (GNDP), U702.49 (EP), X701.2 (GND); also elsewhere on the board
/SCK: U702.4 (SCK_CFG2); also elsewhere on the board
/VAA: C704.1, C708.1, C709.1, C710.1, C711.1, C712.1, C713.1, U702.21 (VS), U702.40 (VS); also elsewhere on the board
/base-motor/5VOUT: C707.1, R703.2, U702.33 (5VOUT)
/base-motor/BMA1: J702.4, U702.46 (OA1)
/base-motor/BMA2: J702.3, U702.42 (OA2)
/base-motor/BMB1: J702.2, U702.15 (OB1)
/base-motor/BMB2: J702.1, U702.19 (OB2)
/base-motor/BRA: R701.1, U702.44 (BRA)
/base-motor/BRB: R702.1, U702.17 (BRB)
/base-motor/CLOCK: U702.2 (CLK), X701.3 (OUT)
/base-motor/CPI: C703.2, U702.37 (CPI)
/base-motor/CPO: C703.1, U702.35 (CP0)
/base-motor/REFL: J701.2, U701.2 (IN)
/base-motor/REFL_DEBOUNCED: U701.3 (OUT), U702.8 (REFL_STEP)
/base-motor/VCP: C704.2, U702.38 (VCP)
/~BASE_MOTOR_CS: R704.2, U702.3 (~CS_CFG3); also elsewhere on the board

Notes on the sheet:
1.64 A RMS

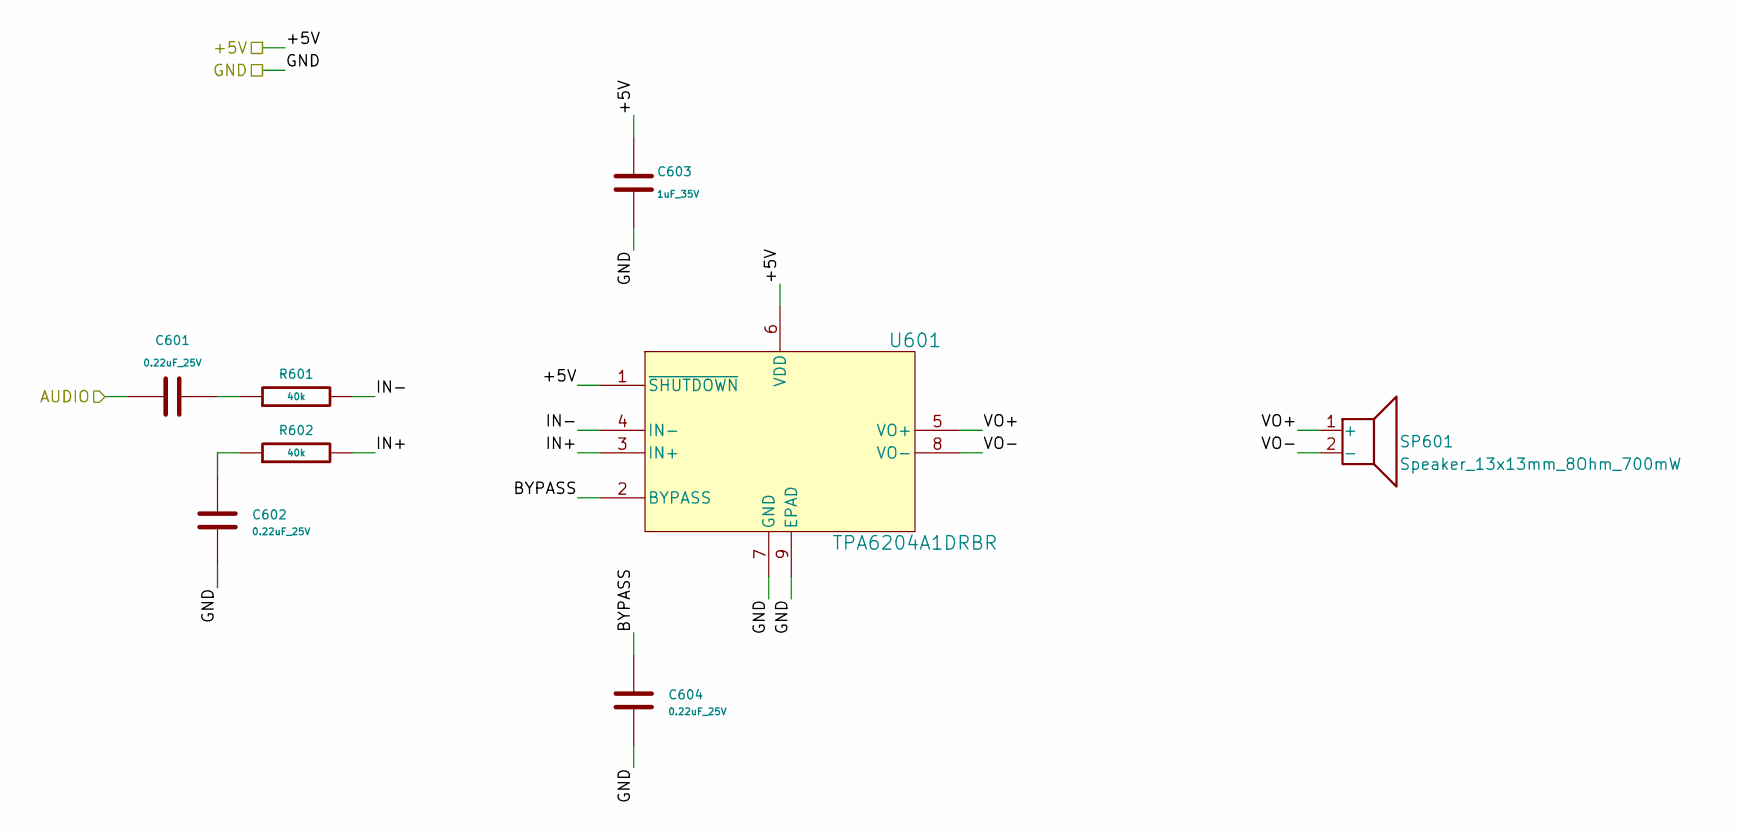
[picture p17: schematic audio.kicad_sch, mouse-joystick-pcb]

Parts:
C601, C602, C604: 0.22uF_25V; C_0402_1005Metric; Manufacturer Part Number GRT155C81E224KE01D; LCSC C126623
C603: 1uF_35V; C_0402_1005Metric; Manufacturer Part Number CL05A105KL5NRNC; LCSC C307413
R601, R602: 40k; R_0603_1608Metric; Manufacturer Part Number SCR0603F40K; LCSC C3016445
SP601: Speaker_13x13mm_8Ohm_700mW; Speaker_13x13mm_KLJ-01304T-08R07W; Manufacturer Part Number KLJ-01304T-08R07W; LCSC C18186315
U601: TPA6204A1DRBR; DRB8_1P75X1P5; Manufacturer Part Number TPA6204A1DRBR; LCSC C12400

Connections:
/+5V: C603.1, U601.1 (~SHUTDOWN), U601.6 (VDD); also elsewhere on the board
/AUDIO: C601.1; also elsewhere on the board
/GND: C602.1, C603.2, C604.1, U601.7 (GND), U601.9 (EPAD); also elsewhere on the board
/audio/BYPASS: C604.2, U601.2 (BYPASS)
/audio/IN+: R602.2, U601.3 (IN+)
/audio/IN-: R601.2, U601.4 (IN-)
/audio/VO+: SP601.1 (+), U601.5 (VO+)
/audio/VO-: SP601.2 (-), U601.8 (VO-)
unnamed: C601.2, R601.1
unnamed: C602.2, R602.1

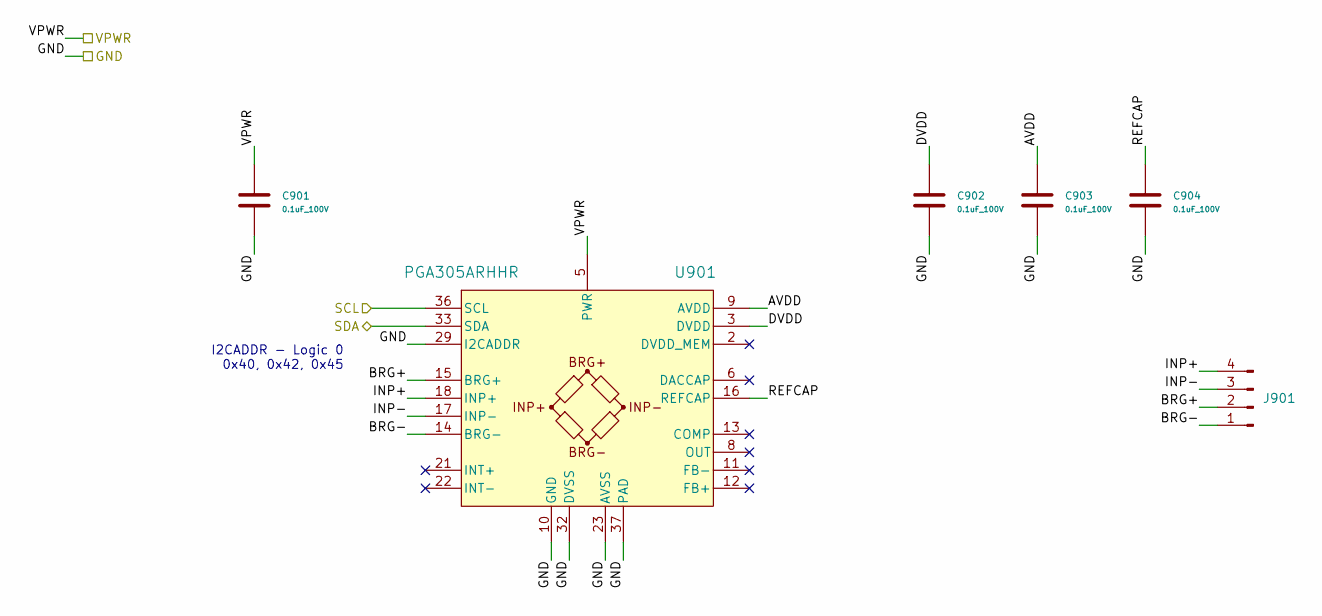
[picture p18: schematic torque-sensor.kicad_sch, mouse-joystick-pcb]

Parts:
C901, C902, C903, C904: 0.1uF_100V; C_0402_1005Metric; Manufacturer Part Number GRM155R62A104KE14D; LCSC C162178
J901: Conn_01x04_P3.5mm_TBH_Horizontal_Screw; PhoenixContact_MC_1,5_4-G-3.5_1x04_P3.50mm_Horizontal_Screw; Manufacturer Part Number 1844236; LCSC C480590
U901: PGA305ARHHR; RHH0036C; Manufacturer Part Number PGA305ARHHR; LCSC C2678416

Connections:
/GND: C901.2, C902.2, C903.2, C904.2, U901.10 (GND), U901.23 (AVSS), U901.29 (I2CADDR), U901.32 (DVSS), U901.37 (PAD); also elsewhere on the board
/SCL: U901.36 (SCL); also elsewhere on the board
/SDA: U901.33 (SDA); also elsewhere on the board
/VAA: C901.1, U901.5 (PWR); also elsewhere on the board
/torque-sensor/AVDD: C903.1, U901.9 (AVDD)
/torque-sensor/BRG+: J901.2, U901.15 (BRG+)
/torque-sensor/BRG-: J901.1, U901.14 (BRG-)
/torque-sensor/DVDD: C902.1, U901.3 (DVDD)
/torque-sensor/INP+: J901.4, U901.18 (INP+)
/torque-sensor/INP-: J901.3, U901.17 (INP-)
/torque-sensor/REFCAP: C904.1, U901.16 (REFCAP)

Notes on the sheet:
I2CADDR - Logic 0 0x40, 0x42, 0x45

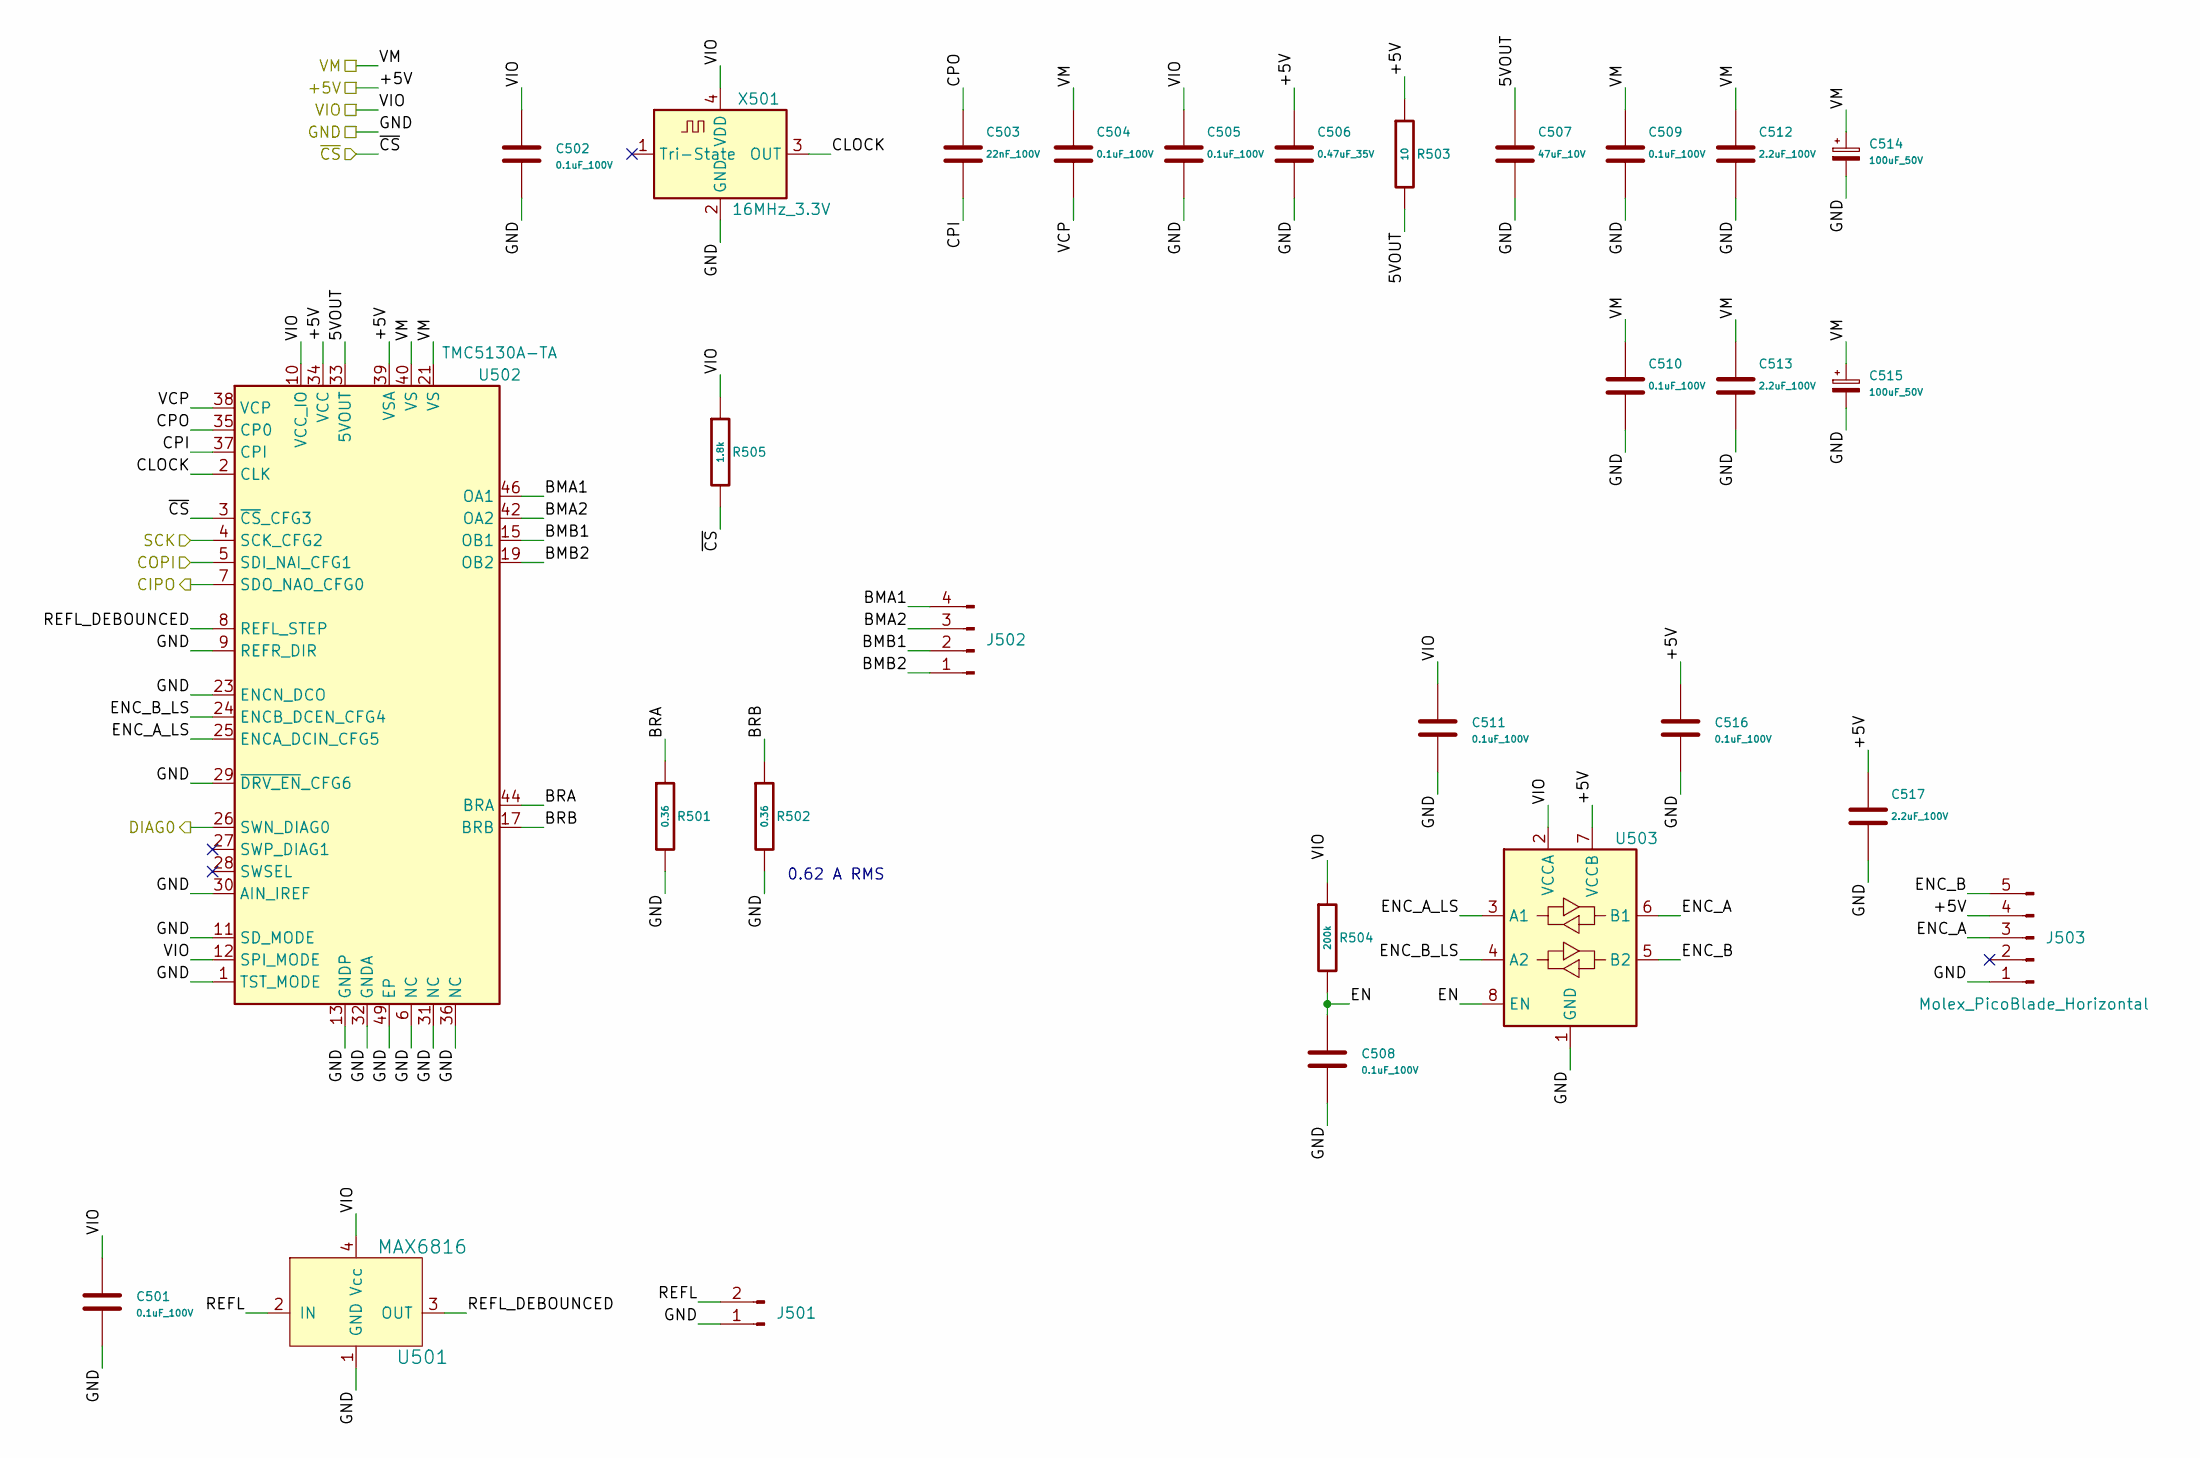
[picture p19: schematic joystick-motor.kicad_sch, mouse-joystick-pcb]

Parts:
C501, C502, C504, C505, C508, C509, C510, C511, C516: 0.1uF_100V; C_0402_1005Metric; Manufacturer Part Number GRM155R62A104KE14D; LCSC C162178
C503: 22nF_100V; C_0603_1608Metric; Manufacturer Part Number GCM188R72A223KA37D; LCSC C161234
C506: 0.47uF_35V; C_0402_1005Metric; Manufacturer Part Number GRT155R6YA474KE01D; LCSC C711580
C507: 47uF_10V; C_0805_2012Metric; Manufacturer Part Number CGA0805X5R476M100MT; LCSC C6119904
C512, C513, C517: 2.2uF_100V; C_0805_2012Metric; Manufacturer Part Number GRM21BD72A225KE01L; LCSC C2981733
C514, C515: 100uF_50V; CAP_EEEHAH101UAP; Manufacturer Part Number EEEHAH101UAP; LCSC C336425
J501: Conn_01x02_P3.5mm_TBH_Horizontal_Screw; PhoenixContact_MC_1,5_2-G-3.5_1x02_P3.50mm_Horizontal_Screw; Manufacturer Part Number 1844210; LCSC C3584780
J502: Conn_01x04_P3.5mm_TBH_Horizontal_Screw; PhoenixContact_MC_1,5_4-G-3.5_1x04_P3.50mm_Horizontal_Screw; Manufacturer Part Number 1844236; LCSC C480590
J503: Molex_PicoBlade_Horizontal; MOLEX_0532610571; Manufacturer Part Number 0532610571; LCSC C17256390
R501, R502: 0.36; R_1206_3216Metric; Manufacturer Part Number RL1206FR-070R36L; LCSC C327079
R503: 10; R_0402_1005Metric; Manufacturer Part Number RC0402FR-0710RL; LCSC C138066
R504: 200k; R_0402_1005Metric; Manufacturer Part Number 0402WGF2003TCE; LCSC C25764
R505: 1.8k; R_0402_1005Metric; Manufacturer Part Number ERJ2GEJ182X; LCSC C409855
U501: MAX6816; SOT192P237X122-4N; Manufacturer Part Number MAX6816EUS+T; LCSC C41637
U502: TMC5130A-TA; TQFP-48-1EP_7x7mm_P0.5mm_EP5x5mm_ThermalVias; Manufacturer Part Number TMC5130A-TA; LCSC C188832
U503: Logic_LevelTranslator_LSF0102DCUR; SOP50P310X90-8N; Manufacturer Part Number LSF0102DCUR; LCSC C964636
X501: 16MHz_3.3V; OSC_ECS-2520S33-160-FN-TR; Manufacturer Part Number ECS-2520S33-160-FN-TR; LCSC C2451298

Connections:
/+3.3V: C501.1, C502.1, C505.1, C511.1, R504.1, R505.1, U501.4 (Vcc), U502.10 (VCC_IO), U502.12 (SPI_MODE), U503.2 (VCCA), X501.4 (VDD); also elsewhere on the board
/+5V: C506.1, C516.1, C517.1, J503.4, R503.1, U502.34 (VCC), U502.39 (VSA), U503.7 (VCCB); also elsewhere on the board
/CIPO: U502.7 (SDO_NAO_CFG0); also elsewhere on the board
/COPI: U502.5 (SDI_NAI_CFG1); also elsewhere on the board
/GND: C501.2, C502.2, C505.2, C506.2, C507.2, C508.2, C509.2, C510.2, C511.2, C512.2, C513.2, C514.2, C515.2, C516.2, C517.2, J501.1, J503.1, R501.2, R502.2, U501.1 (GND), U502.1 (TST_MODE), U502.6 (NC), U502.9 (REFR_DIR), U502.11 (SD_MODE), U502.13 (GNDP), U502.23 (ENCN_DCO), U502.29 (~DRV_EN_CFG6), U502.30 (AIN_IREF), U502.31 (NC), U502.32 (GNDA), U502.36 (NC), U502.48 (GNDP), U502.49 (EP), U503.1 (GND), X501.2 (GND); also elsewhere on the board
/JOYSTICK_MOTOR_DIAG0: U502.26 (SWN_DIAG0); also elsewhere on the board
/SCK: U502.4 (SCK_CFG2); also elsewhere on the board
/VAA: C504.1, C509.1, C510.1, C512.1, C513.1, C514.1, C515.1, U502.21 (VS), U502.40 (VS); also elsewhere on the board
/joystick-motor/5VOUT: C507.1, R503.2, U502.33 (5VOUT)
/joystick-motor/BMA1: J502.4, U502.46 (OA1)
/joystick-motor/BMA2: J502.3, U502.42 (OA2)
/joystick-motor/BMB1: J502.2, U502.15 (OB1)
/joystick-motor/BMB2: J502.1, U502.19 (OB2)
/joystick-motor/BRA: R501.1, U502.44 (BRA)
/joystick-motor/BRB: R502.1, U502.17 (BRB)
/joystick-motor/CLOCK: U502.2 (CLK), X501.3 (OUT)
/joystick-motor/CPI: C503.2, U502.37 (CPI)
/joystick-motor/CPO: C503.1, U502.35 (CP0)
/joystick-motor/EN: C508.1, R504.2, U503.8 (EN)
/joystick-motor/ENC_A: J503.3, U503.6 (B1)
/joystick-motor/ENC_A_LS: U502.25 (ENCA_DCIN_CFG5), U503.3 (A1)
/joystick-motor/ENC_B: J503.5, U503.5 (B2)
/joystick-motor/ENC_B_LS: U502.24 (ENCB_DCEN_CFG4), U503.4 (A2)
/joystick-motor/REFL: J501.2, U501.2 (IN)
/joystick-motor/REFL_DEBOUNCED: U501.3 (OUT), U502.8 (REFL_STEP)
/joystick-motor/VCP: C504.2, U502.38 (VCP)
/~JOYSTICK_MOTOR_CS: R505.2, U502.3 (~CS_CFG3); also elsewhere on the board

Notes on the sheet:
0.62 A RMS

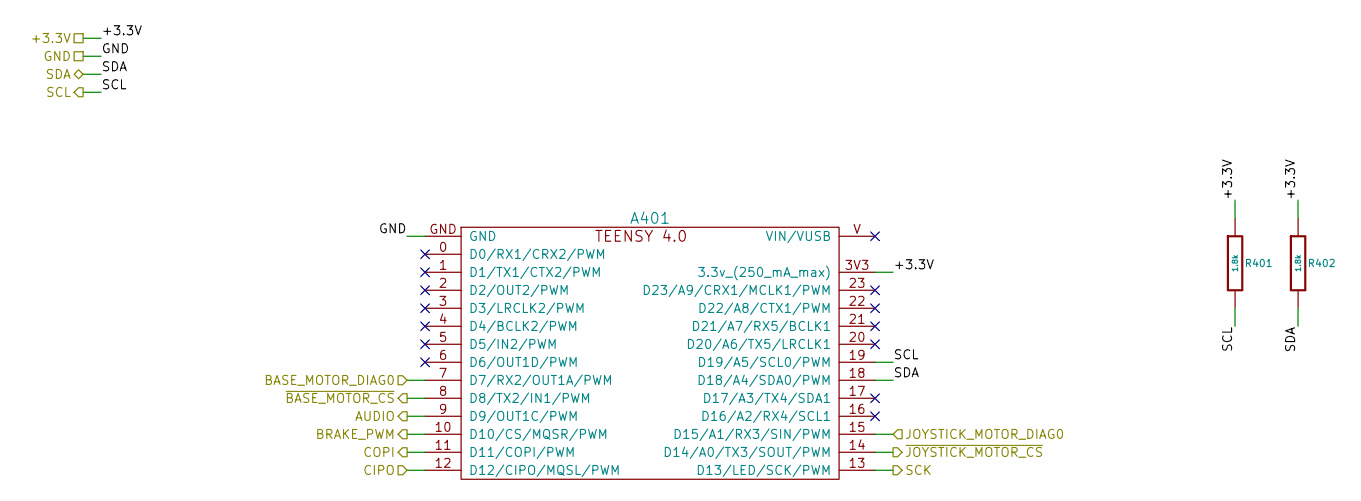
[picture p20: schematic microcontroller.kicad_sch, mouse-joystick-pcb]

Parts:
A401: TEENSY_4.0_HEADERS; Manufacturer Part Number PPPC141LFBN-RC
R401, R402: 1.8k; R_0402_1005Metric; Manufacturer Part Number ERJ2GEJ182X; LCSC C409855

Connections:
/+3.3V: A401.3V3 (3.3v_(250_mA_max)), R401.1, R402.1; also elsewhere on the board
/AUDIO: A401.9 (D9/OUT1C/PWM); also elsewhere on the board
/BASE_MOTOR_DIAG0: A401.7 (D7/RX2/OUT1A/PWM); also elsewhere on the board
/BRAKE_PWM: A401.10 (D10/CS/MQSR/PWM); also elsewhere on the board
/CIPO: A401.12 (D12/CIPO/MQSL/PWM); also elsewhere on the board
/COPI: A401.11 (D11/COPI/PWM); also elsewhere on the board
/GND: A401.GND; also elsewhere on the board
/JOYSTICK_MOTOR_DIAG0: A401.15 (D15/A1/RX3/SIN/PWM); also elsewhere on the board
/SCK: A401.13 (D13/LED/SCK/PWM); also elsewhere on the board
/SCL: A401.19 (D19/A5/SCL0/PWM), R401.2; also elsewhere on the board
/SDA: A401.18 (D18/A4/SDA0/PWM), R402.2; also elsewhere on the board
/~BASE_MOTOR_CS: A401.8 (D8/TX2/IN1/PWM); also elsewhere on the board
/~JOYSTICK_MOTOR_CS: A401.14 (D14/A0/TX3/SOUT/PWM); also elsewhere on the board

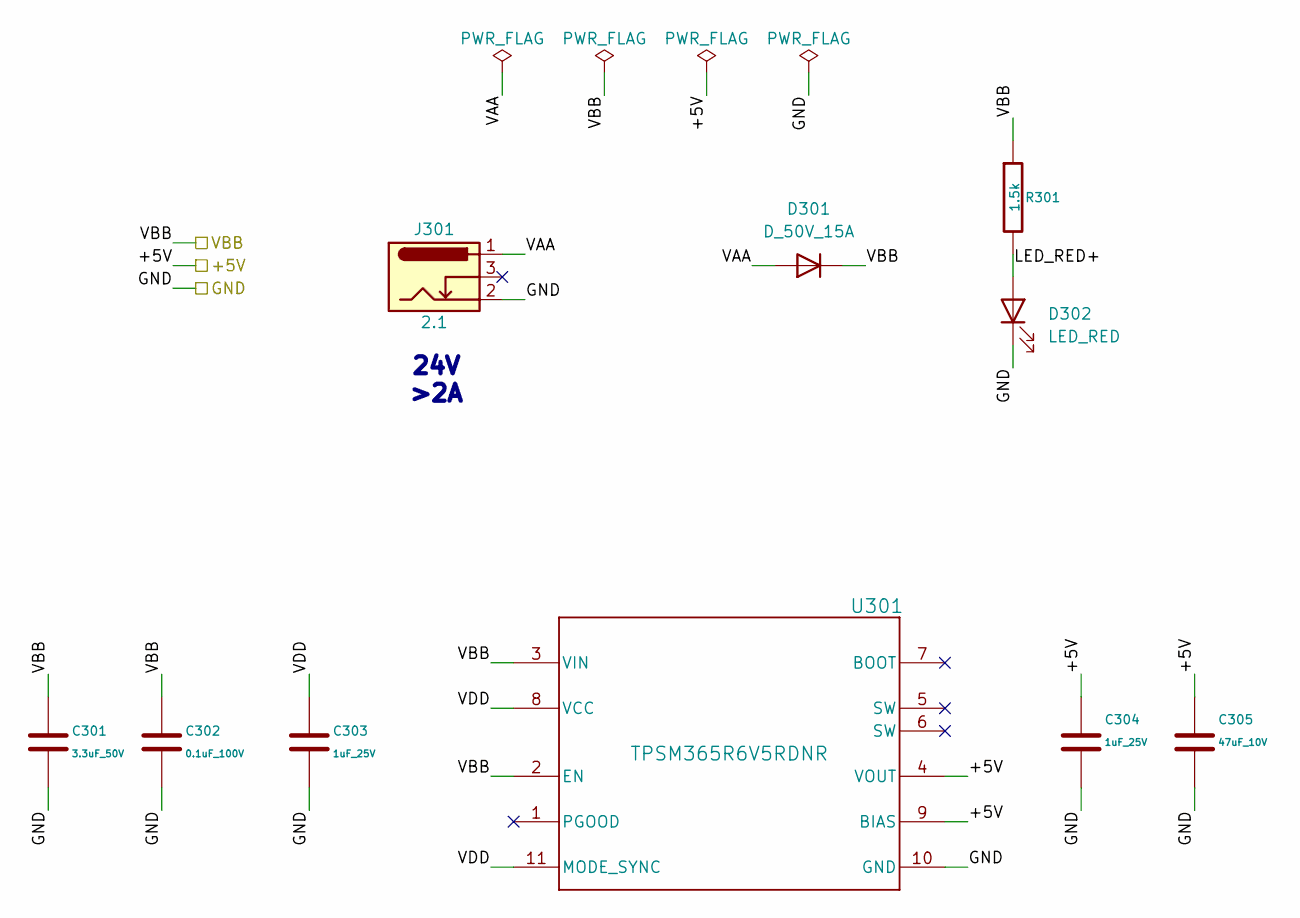
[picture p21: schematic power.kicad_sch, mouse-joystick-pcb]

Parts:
C301: 3.3uF_50V; C_1210_3225Metric; Manufacturer Part Number FS32X335K500EGG; LCSC C1021610
C302: 0.1uF_100V; C_0402_1005Metric; Manufacturer Part Number GRM155R62A104KE14D; LCSC C162178
C303, C304: 1uF_25V; C_0402_1005Metric; Manufacturer Part Number GRT155R61E105KE01D; LCSC C711085
C305: 47uF_10V; C_0805_2012Metric; Manufacturer Part Number CGA0805X5R476M100MT; LCSC C6119904
D301: D_50V_15A; POWERDI5_DIO; Manufacturer Part Number SBRT15U50SP5-13; LCSC C211388
D302: LED_RED; LED_0402-1005_KNB; Manufacturer Part Number APHHS1005SURCK; LCSC C2852592
J301: 2.1; Connector_BarrelJack_XKB_2.1; Manufacturer Part Number DC-005-2.5A-2.0-SMT; LCSC C2880543
R301: 1.5k; R_0805_2012Metric; Manufacturer Part Number ERJP06J152V; LCSC C417005
U301: TPSM365R6V5RDNR; RDN0011A-MFG; Manufacturer Part Number TPSM365R6V5RDNR; LCSC C19078014

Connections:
/+5V: C304.1, C305.1, U301.4 (VOUT), U301.9 (BIAS); also elsewhere on the board
/GND: C301.2, C302.2, C303.2, C304.2, C305.2, D302.1 (K), J301.2, U301.10 (GND); also elsewhere on the board
/VAA: C301.1, C302.1, D301.1 (K), R301.1, U301.2 (EN), U301.3 (VIN); also elsewhere on the board
/power/LED_RED+: D302.2 (A), R301.2
/power/VAA: D301.2 (A), J301.1
/power/VDD: C303.1, U301.8 (VCC), U301.11 (MODE_SYNC)

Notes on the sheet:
24V >2A

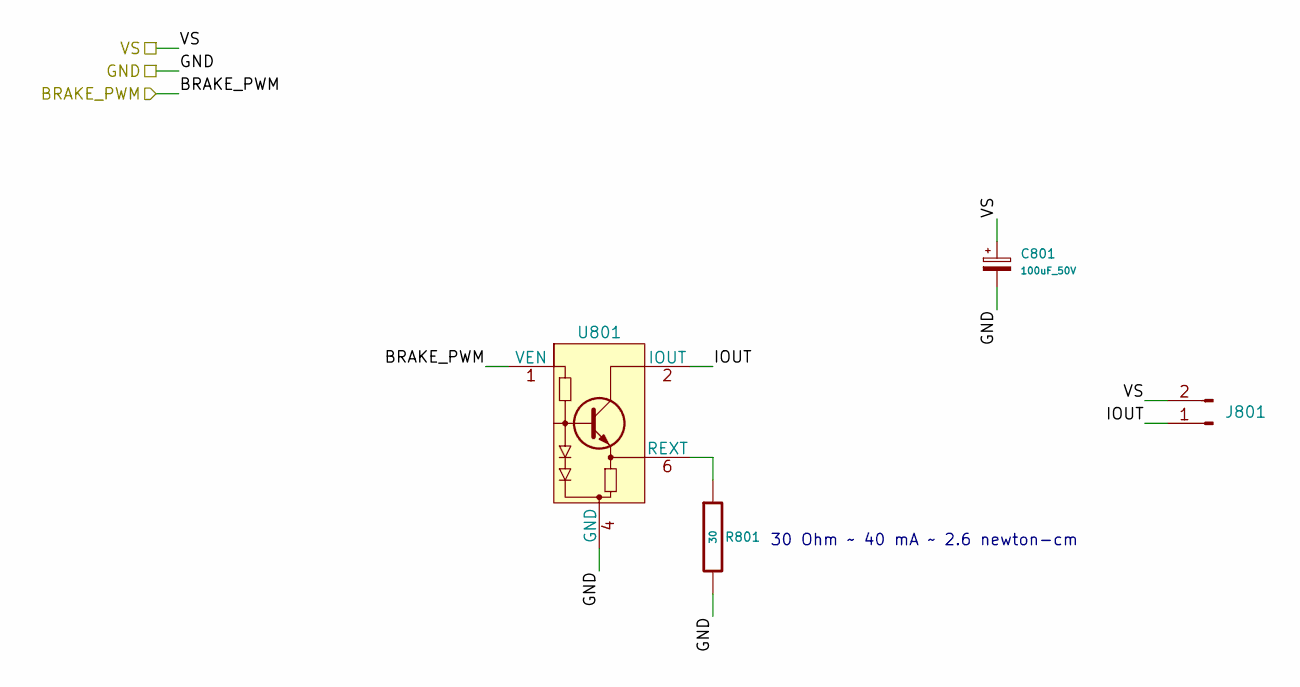
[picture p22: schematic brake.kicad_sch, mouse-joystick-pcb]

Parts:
C801: 100uF_50V; CAP_EEEHAH101UAP; Manufacturer Part Number EEEHAH101UAP; LCSC C336425
J801: Conn_01x02_P3.5mm_TBH_Horizontal_Screw; PhoenixContact_MC_1,5_2-G-3.5_1x02_P3.50mm_Horizontal_Screw; Manufacturer Part Number 1844210; LCSC C3584780
R801: 30; R_0402_1005Metric; Manufacturer Part Number CR0402FF30R0G; LCSC C3036820
U801: 40V_200mA; SC-74-6_1.55x2.9mm_P0.95mm; Manufacturer Part Number BCR421UE6327; LCSC C112923

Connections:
/BRAKE_PWM: U801.1 (VEN); also elsewhere on the board
/GND: C801.2, R801.2, U801.4 (GND); also elsewhere on the board
/VAA: C801.1, J801.2; also elsewhere on the board
/brake/IOUT: J801.1, U801.2 (IOUT), U801.3 (IOUT), U801.5 (IOUT)
unnamed: R801.1, U801.6 (REXT)

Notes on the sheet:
30 Ohm ~ 40 mA ~ 2.6 newton-cm

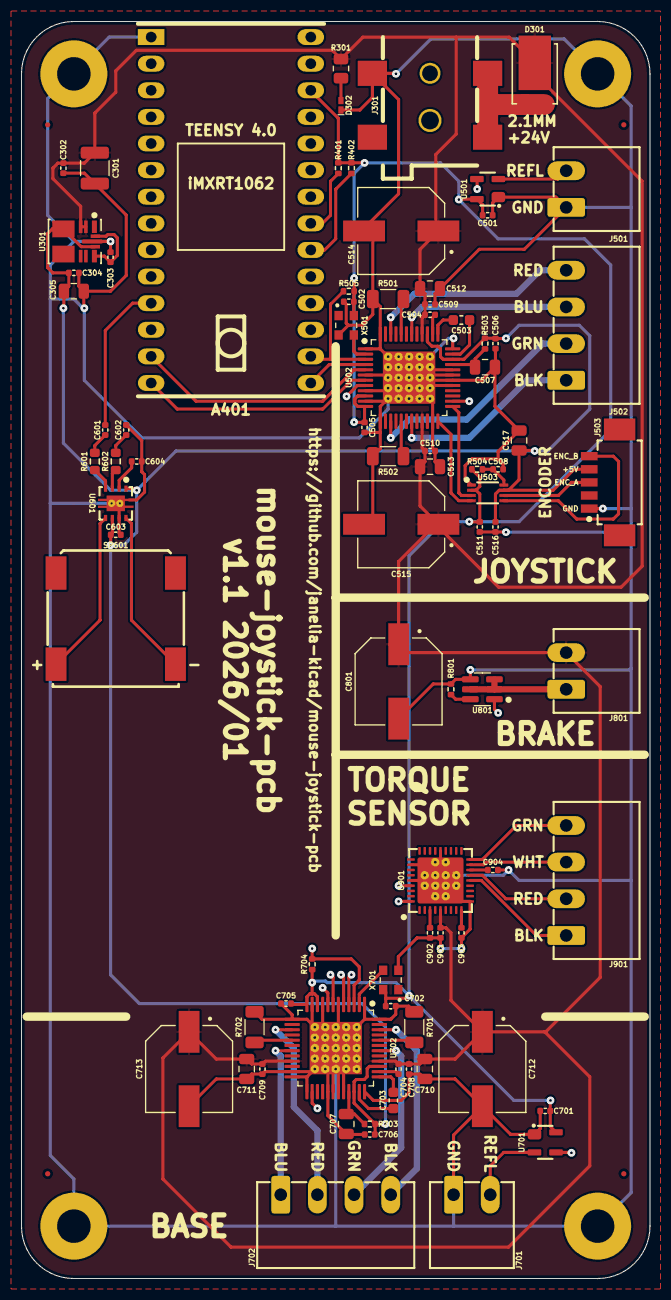
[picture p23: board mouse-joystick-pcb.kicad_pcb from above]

Board: 4 copper layers, 60.0 x 120.0 mm, 90 parts (0 on the bottom side), 65 nets.

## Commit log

2024-08-05 Update kicad config
2024-08-05 Modify schematic for motor-0
    [assembly.kicad_sch, microcontroller.kicad_sch, motor-0.kicad_sch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]
2024-08-27 Make schematic changes
    [motor-0.kicad_sch, power.kicad_sch]
2024-10-01 Add components
    [audio.kicad_sch, microcontroller.kicad_sch, motor-0.kicad_sch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]
2024-10-02 Update motor schematics
    [brake.kicad_sch, motor-1.kicad_sch, mouse-joystick-pcb.kicad_sch]
2024-10-03 Adjust schmatic
    [audio.kicad_sch, brake.kicad_sch, microcontroller.kicad_sch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]
2024-10-07 Update date
    [assembly.kicad_sch, audio.kicad_sch, brake.kicad_sch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]
2024-10-07 Add torque-sensor sheet
    [mouse-joystick-pcb.kicad_sch, torque-sensor.kicad_sch]
2024-10-07 Start wiring schematics
    [brake.kicad_sch, microcontroller.kicad_sch, motor-1.kicad_sch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]
2024-10-08 Finish v1.0 schematic
    [assembly.kicad_sch, audio.kicad_sch, brake.kicad_sch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]
2024-10-08 Initial pcb import
    [mouse-joystick-pcb.kicad_pcb]
2024-10-09 Initial footprint layout
    [assembly.kicad_sch, audio.kicad_sch, brake.kicad_sch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]
2024-10-11 Update Teensy 3D model
    [mouse-joystick-pcb.kicad_pcb]
2024-10-15 Complete some routing
    [assembly.kicad_sch, audio.kicad_sch, brake.kicad_sch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]
2024-10-15 Change encoder connector
    [motor-0.kicad_sch, mouse-joystick-pcb.kicad_pcb]
2024-10-23 Finish routing
    [assembly.kicad_sch, audio.kicad_sch, brake.kicad_sch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]
2024-10-24 Rename schematic sheets
    [assembly.kicad_sch, audio.kicad_sch, base-motor.kicad_sch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]
2024-10-24 Generate metadata
    [jlcpcb-bom.csv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]
2024-10-24 Switch LED resistor to 1.5k
    [jlcpcb-bom.csv, mouse-joystick-pcb.kicad_pcb, power.kicad_sch]
2024-10-24 Update all fabrication files
    [jlcpcb-mouse-joystick-pcb-all-pos.csv, mouse-joystick-pcb-B_Cu.gbl, mouse-joystick-pcb-B_Fab.gbr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]
2024-10-24 Include edge cuts in gerbers
    [mouse-joystick-pcb-B_Cu.gbl, mouse-joystick-pcb-B_Fab.gbr, mouse-joystick-pcb-B_Mask.gbs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]
2024-10-24 Update pcb
    [mouse-joystick-pcb.kicad_pcb]
2026-01-12 Update kicad to verson 9
2026-01-13 Update files based on cluster-pcb
2026-01-13 cluster-pcb -> mouse-joystick-pcb
2026-01-14 Adjust kicad settings
2026-01-14 Update kicad project to new version
    [assembly.kicad_sch, audio.kicad_sch, base-motor.kicad_sch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]
2026-01-15 Update documentation for future v1.1
    [assembly.kicad_sch, audio.kicad_sch, base-motor.kicad_sch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]
2026-06-11 Update channels for kicad 10
